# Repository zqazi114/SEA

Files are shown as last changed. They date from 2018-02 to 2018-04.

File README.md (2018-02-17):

# SEA
<h1>
Creative Machines Lab - Smart Electrode Array
</h1>

<h2>OVERVIEW: </h2>
The goal of this project is to design a digitally controlled large array of electrodes. The project will proceed in 3 phases:

<h3>PHASE 1 - </h3>
1. 2-Layer PCB
2. 2" x 2" 
3. No Electronics
4. 4x4 array of comb electrodes

<h3>PHASE 2 - </h3>
1. 4-Layer PCB
2. 6" x 6" 
3. 2 Port Expanders
4. 5V/3.3V on-board power supplies
5. 12VDC Power input
6. USB interface
7. Jumpers for manual connection
8. Debugging
9. 4x4 array of comb electrodes

<h2>BLOCK DIAGRAM:</h2>

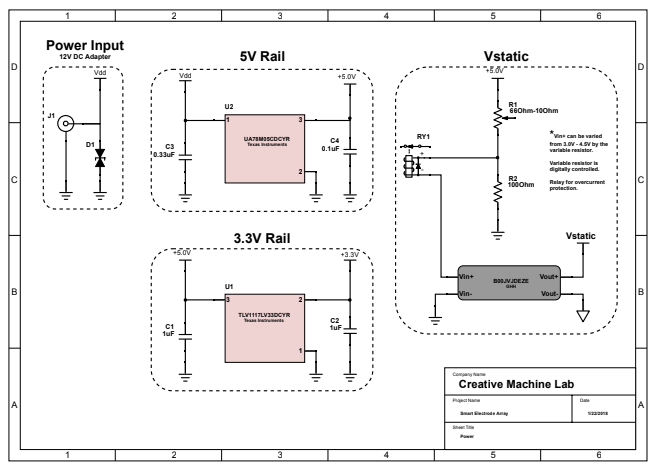
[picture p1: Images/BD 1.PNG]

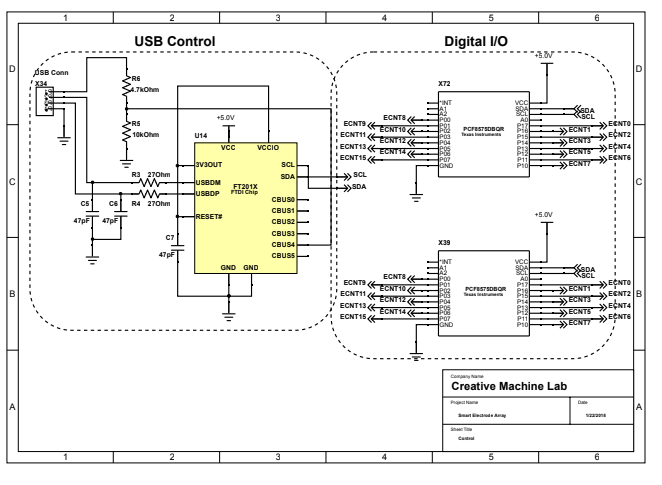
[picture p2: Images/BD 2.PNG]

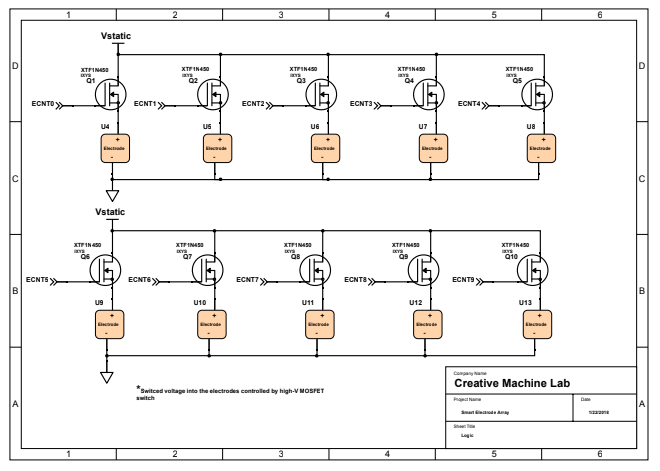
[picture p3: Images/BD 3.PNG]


<h2>FAB A SCHEMATIC:</h2>

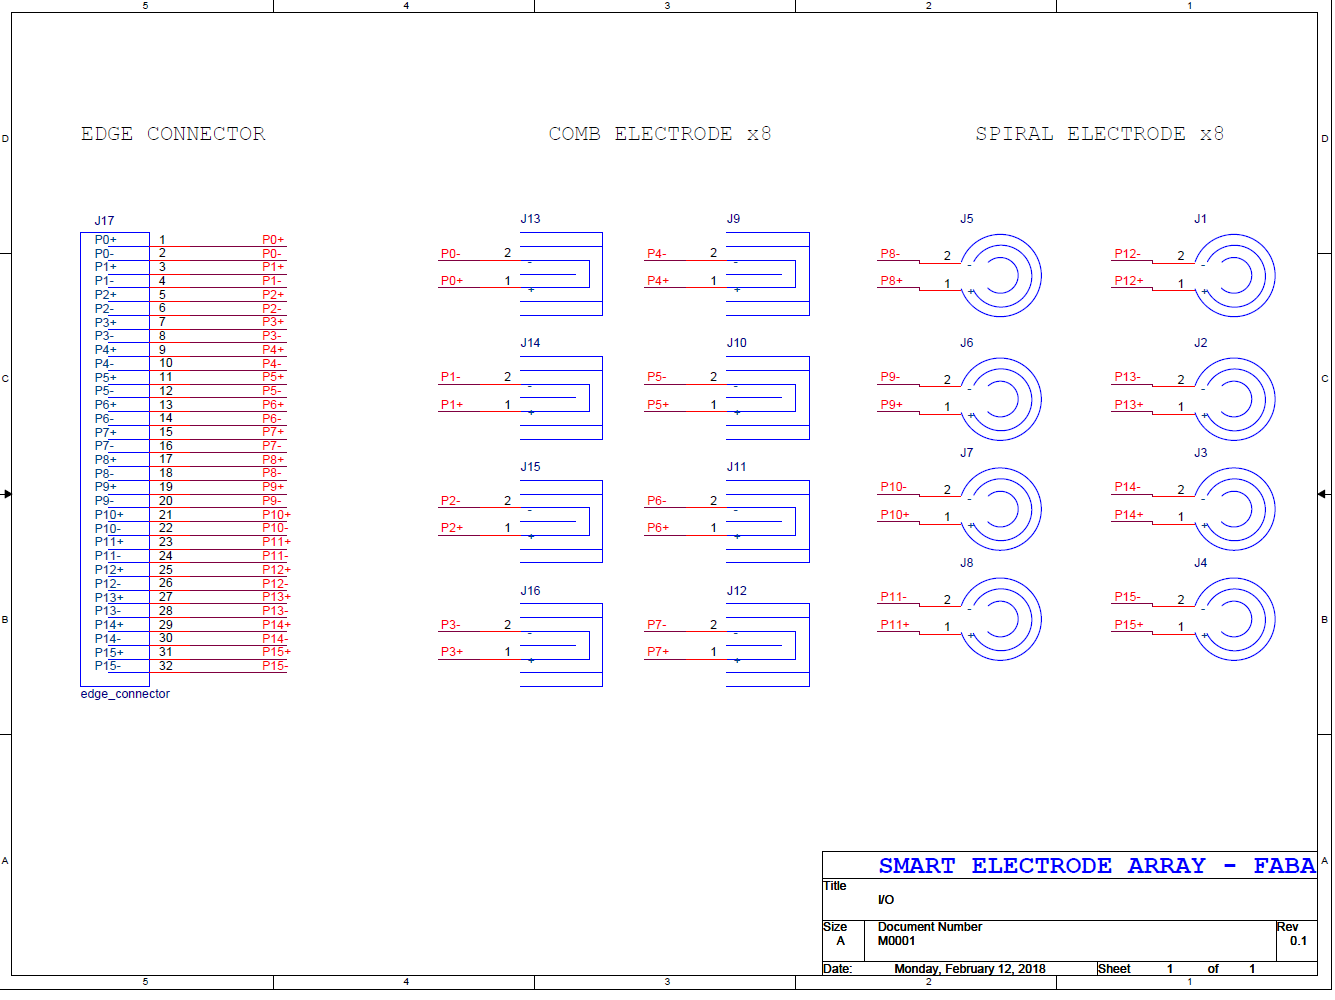
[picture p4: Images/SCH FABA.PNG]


<h2>FAB A LAYOUT:</h2>

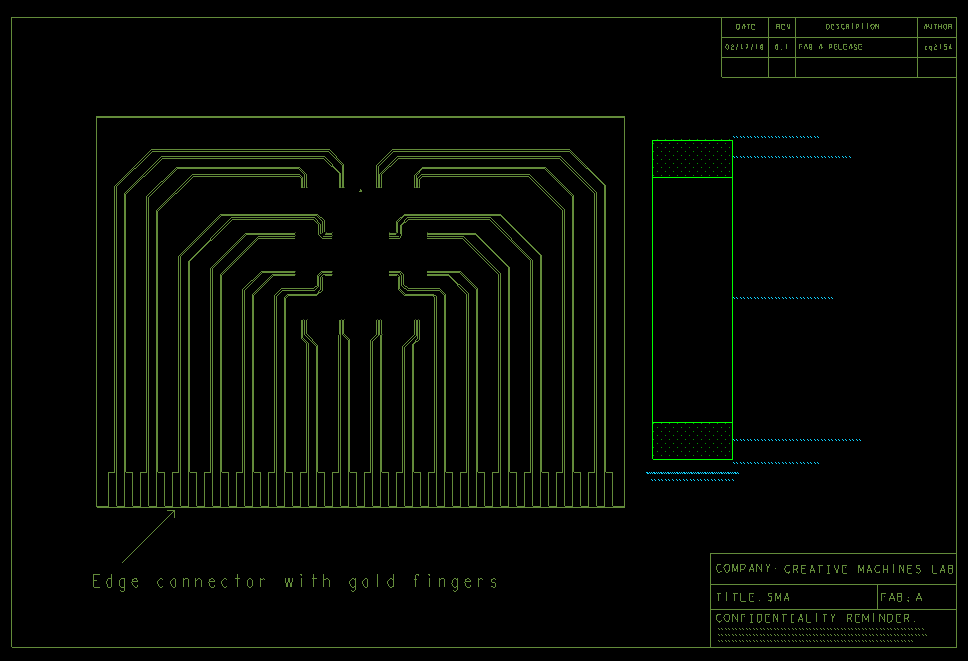
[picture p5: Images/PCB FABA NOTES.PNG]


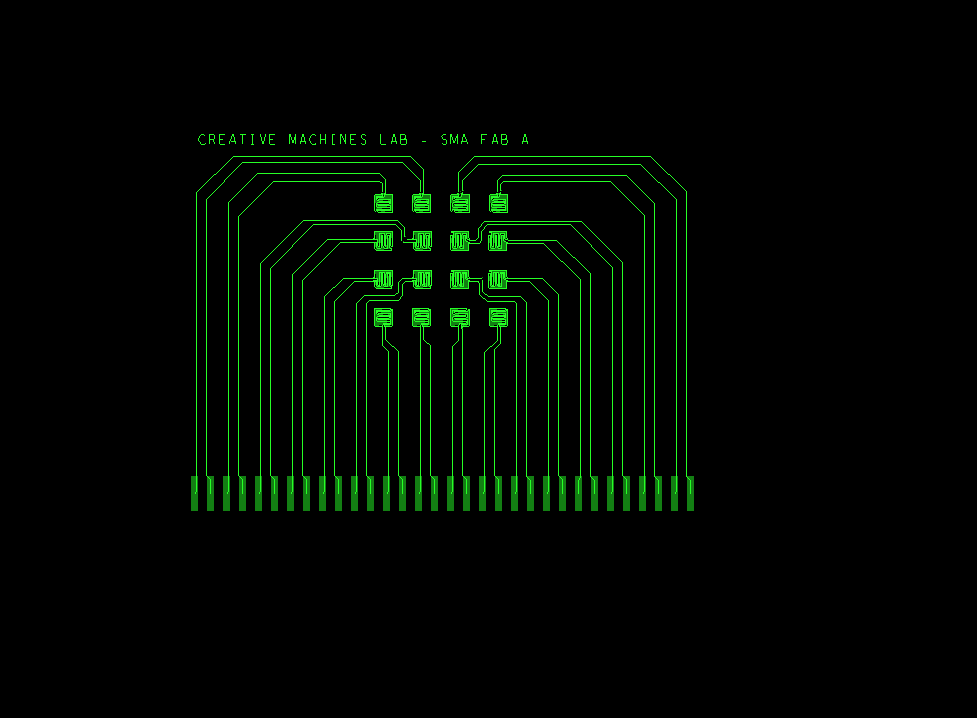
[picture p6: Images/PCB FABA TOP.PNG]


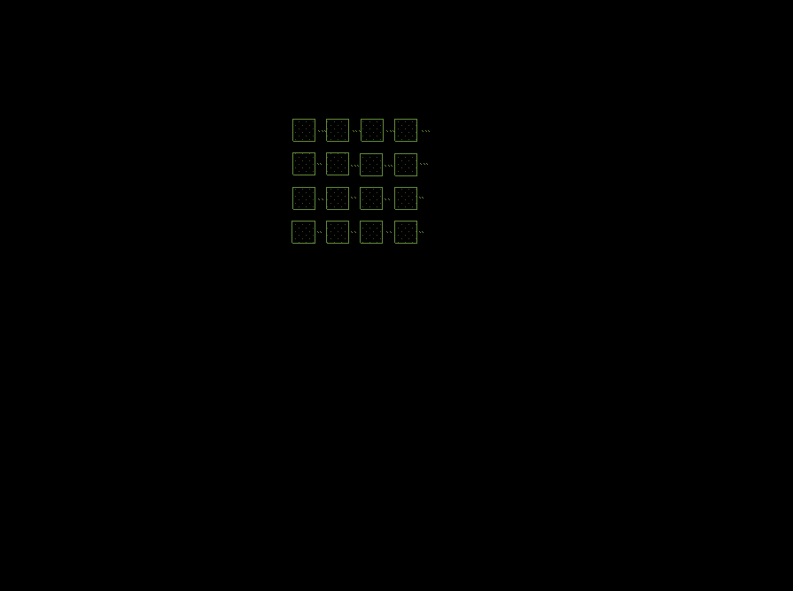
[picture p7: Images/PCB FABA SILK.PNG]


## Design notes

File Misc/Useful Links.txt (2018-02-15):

http://www.flowcad.ch/cms/upload/ApplicationNotes/FlowCAD_AN_PCB_Manufacturing.pdf
https://www.autodesk.com/products/eagle/blog/gerber-nc-drill-pcb-manufacturing-basics-1/
http://www.proto2prod.com/proto2prod/2015/3/18/your-first-prototype-fab-specs-and-gerber-files-13
https://resources.altium.com/pcb-design-blog/how-to-plan-your-pcb-layout-for-a-high-voltage-design
https://resources.altium.com/pcb-design-blog/high-voltage-pcb-design-creepage-and-clearance-distance
http://www.ni.com/tutorial/8584/en/
http://www.4pcb.com/pcb-student-discount.html

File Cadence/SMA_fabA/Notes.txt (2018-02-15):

FAB HOUSE:
http://www.4pcb.com/pcb-prototype-2-4-layer-boards-specials.html
Instructions - 
1. 2 Layer board 60" sq (8" x 8")
2. Minimum of 3
3. FR-4 0.062"
4. 1 oz Cu
5. Green Mask
6. Custom Shape
7. Min 5 mil line/space
8. Min 10 mil hole size
9. No cut-outs
 
1. 4 Layer board 30" sq (6" x 6")
2. Minimum of 4
3. FR-4 0.062"
4. 1 oz Cu
5. Green Mask
6. Custom Shape
7. Min 5 mil line/space
8. Min 10 mil hole size
9. No cut-outs

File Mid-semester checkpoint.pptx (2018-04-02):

## PROTOTYPING

Three Options:
1. PMOS
2. CMOS Inverter
3. Solid State Relay

## OPTION 1 – PMOS

ON STATE :
VIN < VSTAT – VTH ✔
OFF STATE :
VIN > VSTAT – VTH ✖
Unsuccessful.

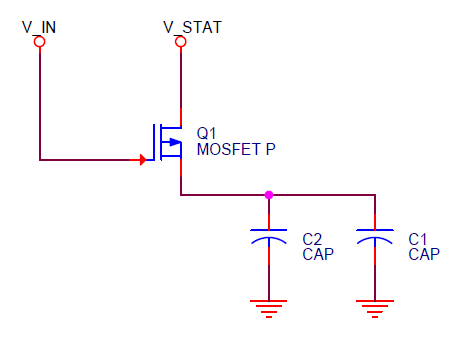
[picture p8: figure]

## OPTION 2 – CMOS

ON STATE :
VIN < VSTAT – VTH ✔
OFF STATE :
VIN > VSTAT – VTH ✖
Unsuccessful.

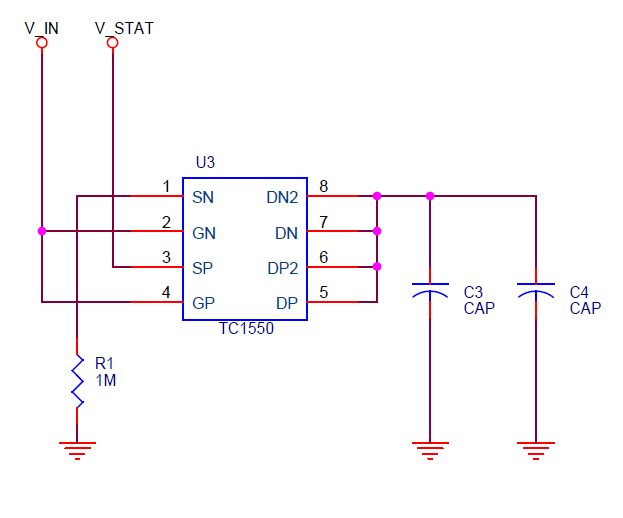
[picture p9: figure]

## OPTION 3 – SSR

ON STATE :
VIN < VSTAT – VTH ✔
OFF STATE :
VIN > VSTAT – VTH ✔
Successful.

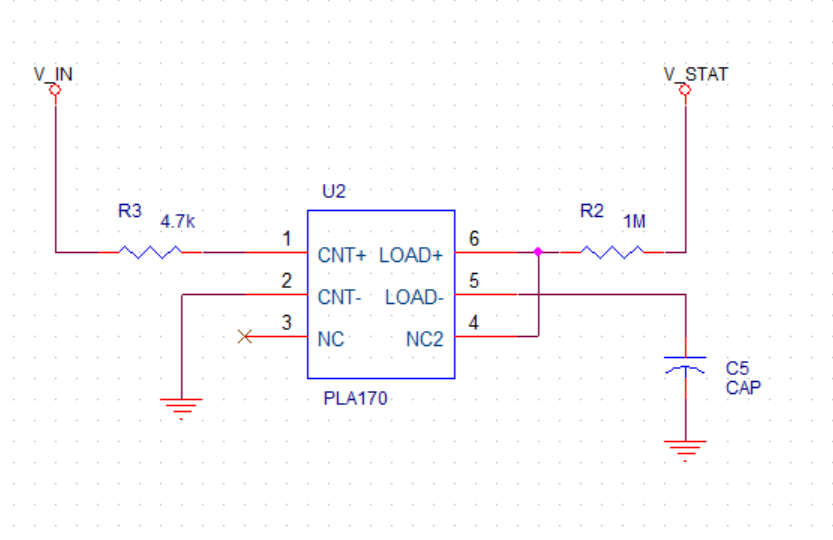
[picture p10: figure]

## PCB DESIGN

We are not expecting static power dissipation
With this scheme, we can experiment with a refresh rate AND measure power dissipation for a parallel On/Off scheme

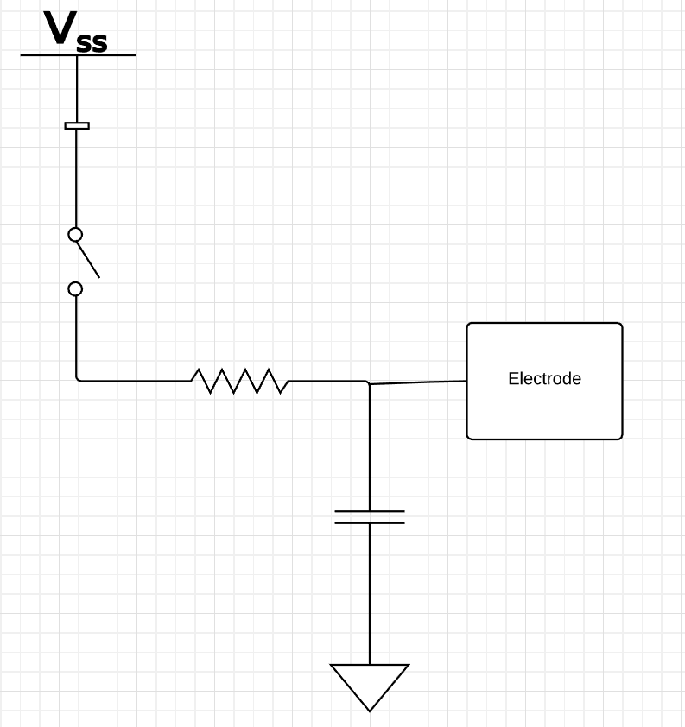
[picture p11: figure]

Off State

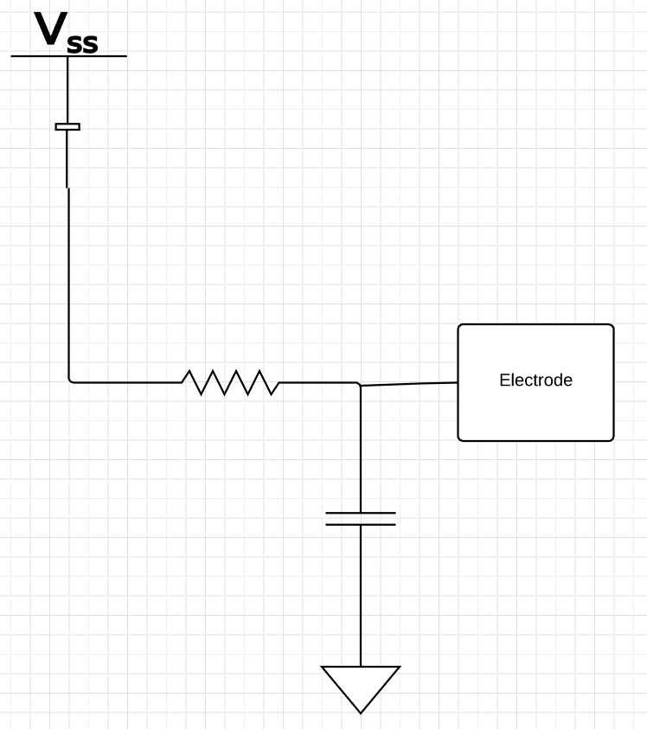
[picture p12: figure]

On State

Circuit

## CHALLENGES

- High inrush current
- Leakage as discharge path

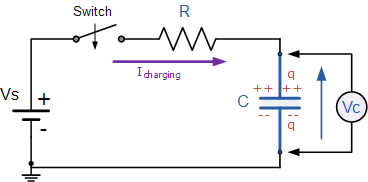
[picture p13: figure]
Image result for rc circuit charging and discharging
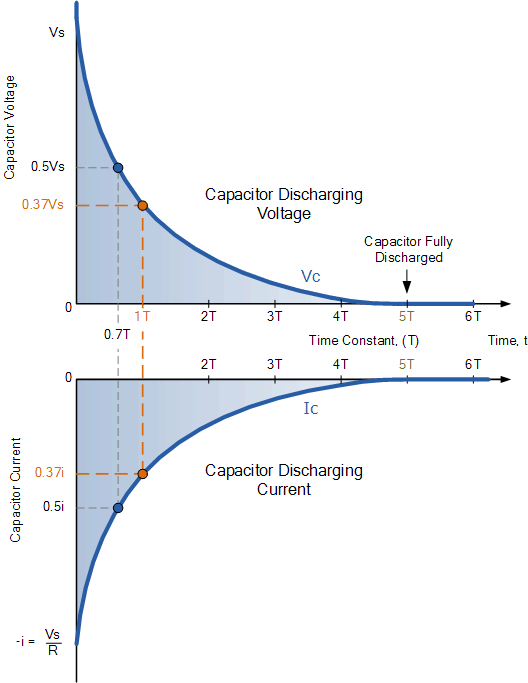
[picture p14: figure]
Image result for rc current plot
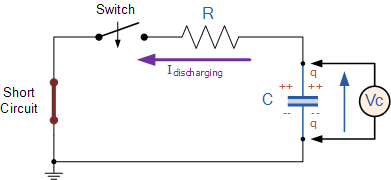
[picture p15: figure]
Related image

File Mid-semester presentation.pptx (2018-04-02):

## Capabilities

Design electronics to digitally control a 4x4 array of electrodes
- 16 independent channels
- Communicate through USB port
- 12VDC power adapter
- Low static power dissipation

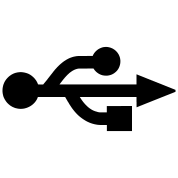
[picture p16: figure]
Image result for usb logo
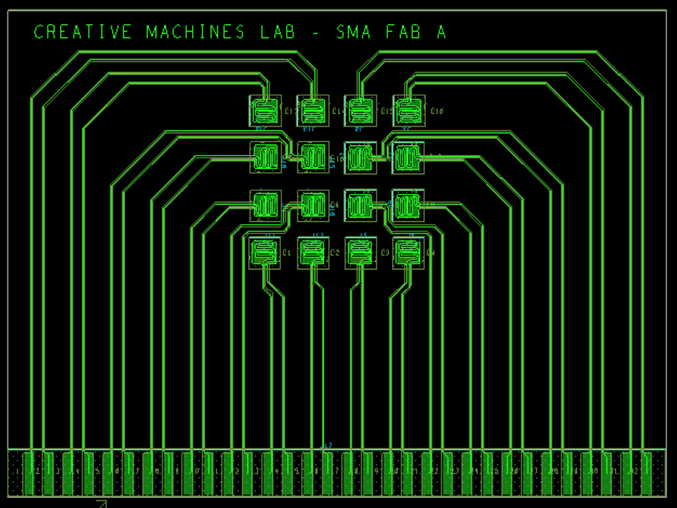
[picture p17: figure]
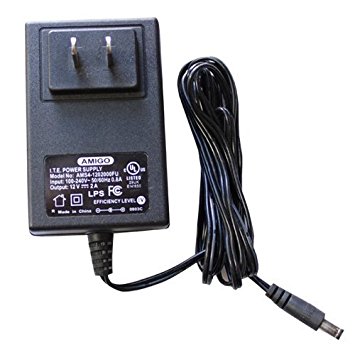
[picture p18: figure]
Image result for 12v dc power adapter

## Block Diagram

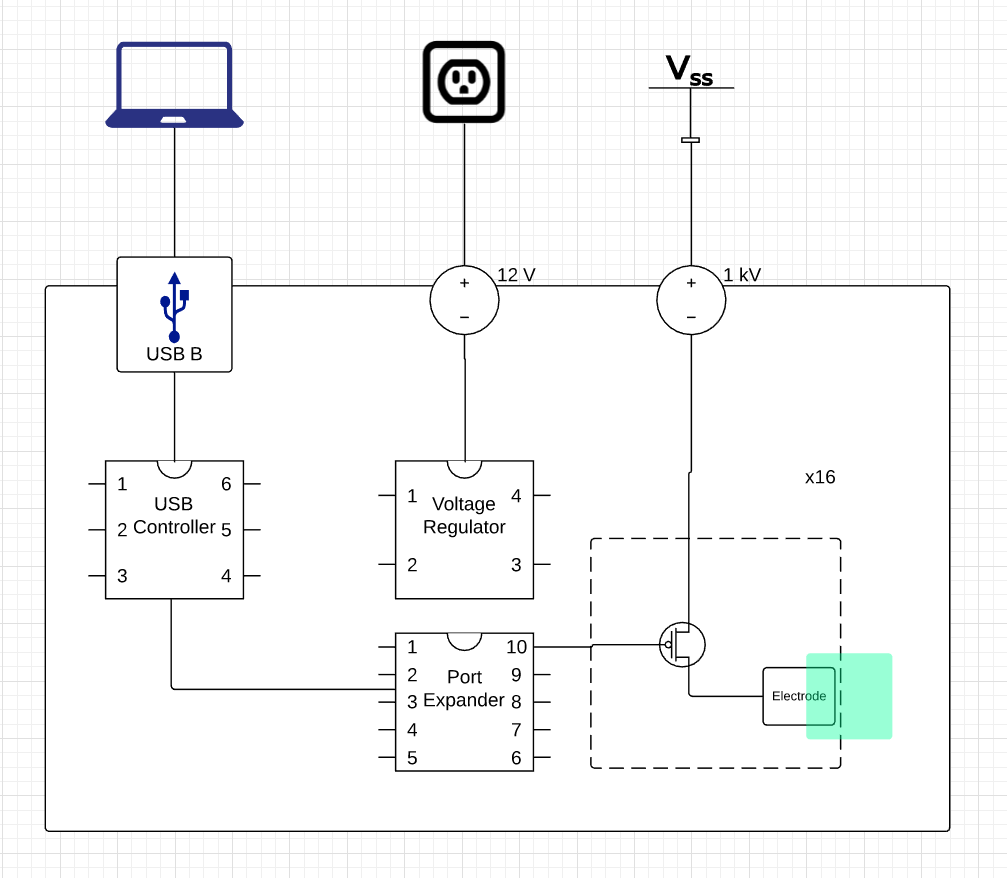
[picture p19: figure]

INPUT
- USB B connector
- 5.5-2.1mm DC jack
IC
- USB Controller
- Port Expander
- VR
- Power Transistors
OUTPUT
- x16 Electrodes

## Prototypes

Test out various dynamic charging schemes
- Single PMOS
- CMOS Inverter
- SSR
{Ongoing}

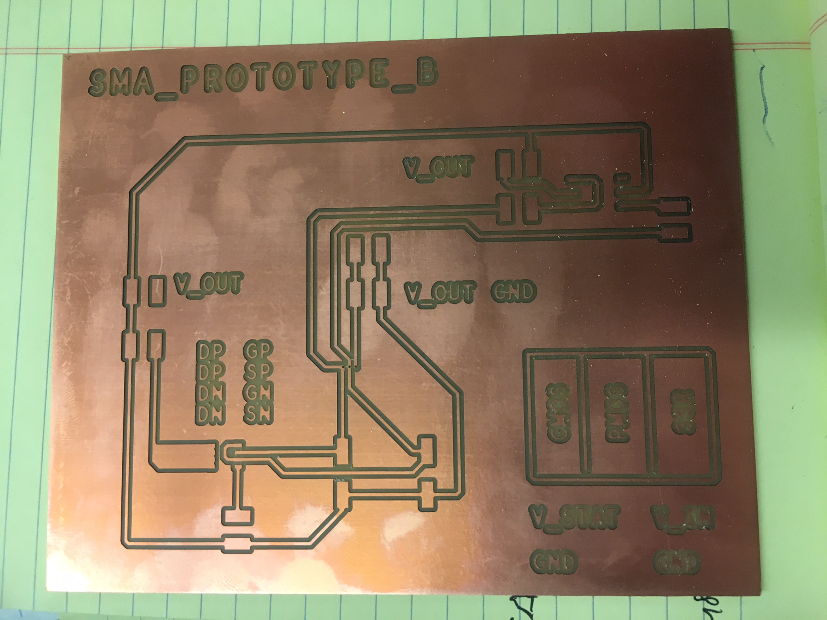
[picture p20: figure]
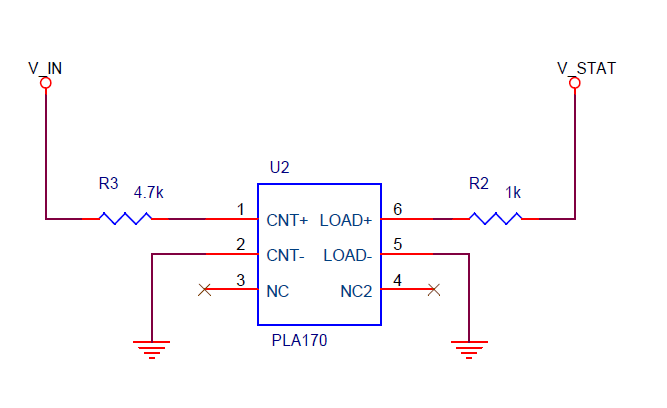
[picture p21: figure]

## Design

Laid out essential components
Completing prototyping activities before
sending out to fab shops

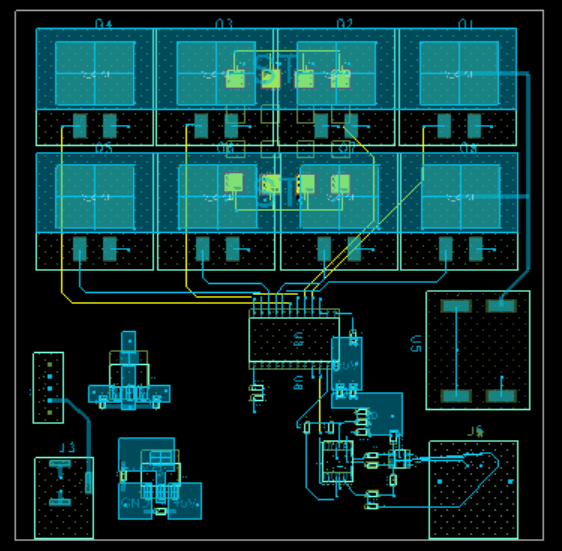
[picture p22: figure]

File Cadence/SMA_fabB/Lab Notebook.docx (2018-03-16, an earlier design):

TOP ISSUES:

# Shared Ground

## Is it alright to connect the high voltage ground to logic ground? Any issues of ground noise coupling?

# Heat loss in MOSFET

## If my MOSFET has an RDS-ON = 25 Ohms, do I risk static power loss during ON/OFF state causing overheating?

## How large should my series resistance be between VSTAT and GND? Do passive components have voltage limits?

## Is there a good design to circumvent static power losses?

# VGS-min required to fully switch MOSFET

## Can the port expander provide sufficient current/voltage to switch the MOSFET?

# Capacitive load of electrode Any risk of back-emf into my MOSFET causing damage?

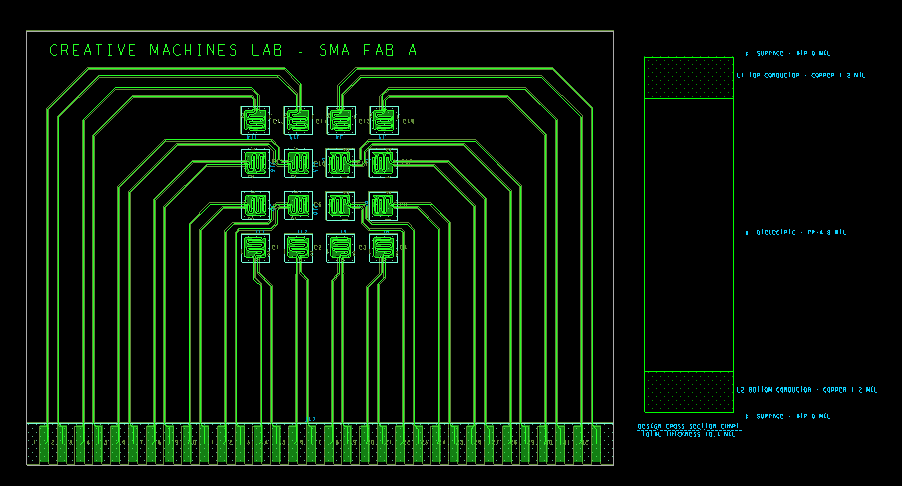
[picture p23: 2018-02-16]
Images/PCB FABA.PNG

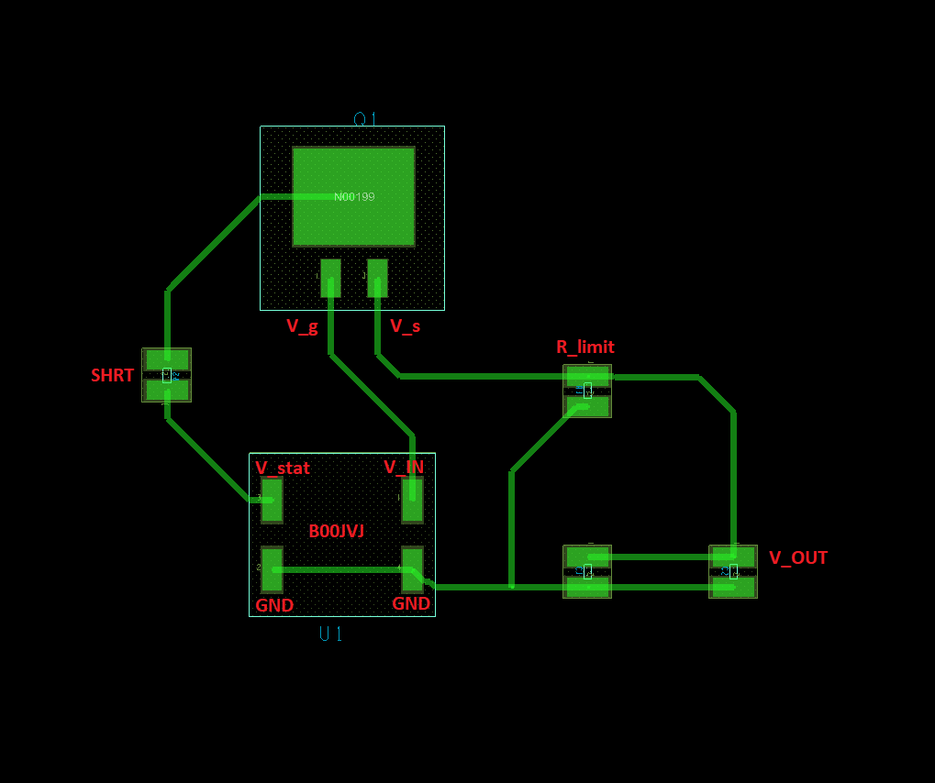
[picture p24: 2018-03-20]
Cadence/SMA_Prototype/Prototype Silkscreen.png

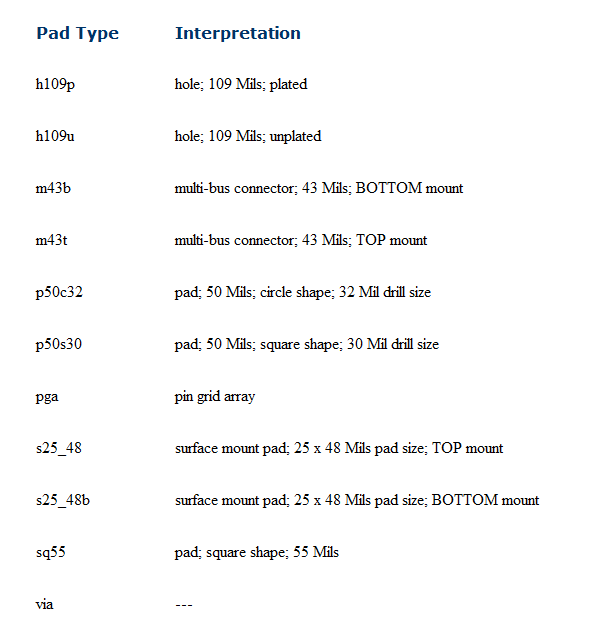
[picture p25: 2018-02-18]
Standards/Pad Naming.PNG

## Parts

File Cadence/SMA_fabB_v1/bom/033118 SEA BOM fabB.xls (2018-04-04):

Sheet: PCBA BOM
Smart Electrode Array BOM (PCBA)
Item # | Ref Des | Qty | Manufacturer | Mfg Part # | Description | Package | Type | Price (USD) | Ext. Price (USD) | Link | Your Instructions
IC
 | U3 | 1 | TI | UA78M05CDCY | IC REG LINEAR 5V 500MA SOT223-4 | SOT-223-4 | SMD | $0.62 | $0.62 | https://www.digikey.com/product-detail/en/texas-instruments/UA78M05CDCY/296-27138-5-ND/1910303 |  | Samples Available
 | U4 | 1 | TI | TLV1117LV33DCYT | IC REG LINEAR 3.3V 1A SOT223-4 | SOT-223-4 | SMD | $0.72 | $0.72 | https://www.digikey.com/product-detail/en/texas-instruments/TLV1117LV33DCYT/296-35976-6-ND/4135114
 | U5 | 1 | YQLTD | B00JVJDEZE | DC Boost Step Up Power Module High Voltage Generator DC 3v-6v To 20kV | Custom | SMD | $8.98 | $8.98 | https://www.amazon.com/Boost-Power-Module-Voltage-Generator/dp/B00JVJDEZE (https://www.digikey.com/product-detail/en/texas-instruments/TLV1117LV33DCYT/296-35976-6-ND/4135114)
 | U8 | 1 | TI | PCF8575DW | IC I/O EXPANDER I2C 16B 24SOIC | SIOC-16 | SMD | $2.86 | $2.86 | https://www.digikey.com/product-detail/en/texas-instruments/PCF8575DW/296-33528-5-ND/1573158
 | U9-U24 | 16 | IXYS | PLA170STR | SSR PCB Mount Single-Pole Relay 800V 100mA | SMD | SMD | $3.39 | $54.24 | https://www.mouser.com/ProductDetail/ixys/pla170str/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
CONNECTOR
 | J3 | 1 | MPD | EJ503A | CONN PWR JACK 2.1X5.5MM SOLDER | Custom | TH | $2.02 | $2.02 | https://www.digikey.com/product-detail/en/mpd-memory-protection-devices/EJ503A/EJ503A-ND/5431753
 | J14 | 1 | C&K | 1103M2S3CQE2 | SWITCH SLIDE SPDT 6A 120V | Custom | TH | $3.64 | $3.64 | https://www.digikey.com/products/en?keywords=1103M2S3CQE2
 | J31 | 1 | Amphenol | 67997-410HLF | CONN HEADER 10POS .100 STR TIN | Custom | TH | $0.27 | $0.27 | https://www.digikey.com/product-detail/en/amphenol-fci/67997-410HLF/609-3243-ND/1878475
 | J32-J34 | 3 | Wurth | 61300311121 | CONN HEADER 3 POS 2.54 | Custom | TH | $0.13 | $0.39 | https://www.digikey.com/product-detail/en/wurth-electronics-inc/61300311121/732-5316-ND/4846825
 | J35 | 1 | Sullins | SBH11-PBPC-D08-ST-BK (https://www.digikey.com/product-detail/en/sullins-connector-solutions/SBH11-PBPC-D08-ST-BK/S9171-ND/1990064) | CONN HEADER 2.54MM 16POS GOLD | Custom | TH | $0.42 | $0.42 | https://www.digikey.com/product-detail/en/sullins-connector-solutions/SBH11-PBPC-D08-ST-BK/S9171-ND/1990064
 | NA | 50 | Sullins | STC02SYAN | CONN JUMPER SHORTING TIN | Custom | TH | $0.10 | $5.00 | https://www.digikey.com/product-detail/en/sullins-connector-solutions/STC02SYAN/S9000-ND/76372
PASSIVE
 | D5 | 1 | Littelfuse Inc. | SA14A | TVS DIODE 14VWM 23.2VC DO204AC | DO-204AC | TH | $0.46 | $0.46 | https://www.digikey.com/product-detail/en/littelfuse-inc/SA14A/SA14ACT-ND/2770381
 | C5 | 1 | TDK | C3216X7R2A334K130AA | 0.33uF Ceramic Cap | 1206 | SMD | $0.57 | $0.57 | https://www.digikey.com/product-detail/en/tdk-corporation/C3216X7R2A334K130AA/445-4464-1-ND/2042260
 | C6,C17 | 2 | Samsung | CL31B104KBCNNNC | 0.1uF Ceramic Cap | 1206 | SMD | $0.10 | $0.20 | https://www.digikey.com/product-detail/en/samsung-electro-mechanics/CL31B104KBCNNNC/1276-1017-1-ND/3889103
 | C7,C8,C16 | 3 | Murata | C1206C105K4RACTU | 1uF Ceramic Cap | 1206 | SMD | $0.23 | $0.69 | https://www.digikey.com/product-detail/en/kemet/C1206C105K4RACTU/399-1254-1-ND/411529
 | C18-C49 | 32 | Kemet | C1206C223KDRACTU | CAP CER 0.022UF 1KV X7R 1206 | 1206 | SMD | $0.38 | $12.16 | https://www.digikey.com/product-detail/en/kemet/C1206C223KDRACTU/399-6746-1-ND/3083920
 | R12,R13,R15 | 3 | Yageo | RC1206JR-074K7L | 4.7kOhm Resistor | 1206 | SMD | $0.10 | $0.30 | https://www.digikey.com/product-detail/en/yageo/RC1206JR-074K7L/311-4.7KERCT-ND/732242
 | R14 | 1 | Yageo | RC1206JR-0710KL | 10kOhm Resistor | 1206 | SMD | $0.10 | $0.10 | https://www.digikey.com/product-detail/en/yageo/RC1206JR-0710KL/311-10KERCT-ND/732156
 | R16-R47 | 32 | Welwyn | HVC1206-10MJT3/ | 10M 1kV | 1206 | SMD | $0.78 | $24.96 | https://www.mouser.com/ProductDetail/Welwyn-Components-TT-Electronics/HVC1206-10MJT3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
 | D7 | 1 | QT | QBLP615-R | Red LED | 1206 | SMD | $0.10 | $0.10 | https://www.digikey.com/product-detail/en/qt-brightek-qtb/QBLP615-R/1516-1076-2-ND/4814674
 | D6 | 1 | QT | QBLP615-IB | Blue LED | 1206 | SMD | $0.50 | $0.50 | https://www.digikey.com/product-detail/en/qt-brightek-qtb/QBLP615-IB/1516-1072-1-ND/4814799
 | D4 | 1 | QT | QBLP615-Y | Yellow LED | 1206 | SMD | $0.41 | $0.41 | https://www.digikey.com/product-detail/en/qt-brightek-qtb/QBLP615-Y/1516-1077-1-ND/4814804
 | J15-J30 | 16 | NA | NA | Comb Electrode | NA | SMD | $0.00 | $0.00
 |  |  |  |  |  |  |  | TOTAL | $119.61
 |  |  |  |  |  |  |  | w/o MOS | $65.37

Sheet: Other BOM
Smart Electrode Array BOM (OTHER)
Item # | Qty | Manufacturer | Mfg Part # | Description | Price (USD) | Link | Your Instructions
1 | 1 | XP-Power | VEL05US120-US-JA | AC/DC WALL MOUNT ADAPTER 12V 5W | $6.50 | https://www.digikey.com/product-detail/en/xp-power/VEL05US120-US-JA/1470-2774-ND/5023716
2 | 1 | Aardvark | TP240141 | Aardvark I2C/SPI Host Adapter | $285.00 | https://www.totalphase.com/catalog/product/view/id/2/s/aardvark-i2cspi/
3
4
5
 |  |  |  | TOTAL | $291.50

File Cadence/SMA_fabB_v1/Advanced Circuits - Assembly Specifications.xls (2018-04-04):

 | ~ PCB Fabrication & Assembly All Under One Roof ~
Assembly Order Type
X | Full Turn-Key | Select - if you want Advanced Circuits / One Stop Assembly to purchase ALL components.
(Minimum quantity is 5) |  | Please request budgetary quotes and quotes from preliminary BOMS as labor only.
 |  | We will be pleased to quote material pricing once your BOM has been finalized.
 | Labor Only | Select - if you would like a LABOR ONLY QUOTE and you will be supplying / sending
(No Minimum Qty) |  | ALL components.
 | Partial Turn-Key | Select - if you will be sending some components. ***
*** - Identify the components you will be supplying on your BOM as “Customer Supplied”. If you have components you do not
want installed, identify them as DNI or DNP (Do Not Install / Populate).
Assembly Type |  | X | New Assembly |  |  |  | Previous Work Order / PO #
Re-orders without change (RONC) - Labor Discounts may apply
Assemblies will be manufactured in accordance with IPC 610 Class II Workmanship Standards
 |  | Build Qty | 1 |  | Build Qty | 5 |  | Build Qty | 10
These quantities will be shipped as a single lot / weekly / monthly / quarterly / annually
Assembly Part Number
Revision
PCB Dimension **(inches) |  | 4.19 |  |  | X | 3.57
** - If your PCB has a dimension less than < 2” it must be panelized in an array for assembly or it may increase your labor
cost, contact your Assembly Sales Manager or Associate for array details.
Depanel |  |  | Yes | X | No |  | N/A
(PCBAs being assembled in an array can be shipped individually or in the complete array)
SMT Components on both sides |  |  | Yes | X | No
Lead Free Processing (RoHS) ** |  |  | Yes |  | No | X
** - Lead-free BGAs will require (RoHS) lead-free processing
ITAR Compliance – Code M |  |  | Yes |  | No | X
Click Here - For more information whether or not your assembly data is ITAR-controlled go to http://en.wikipedia.org/wiki/ITAR.
Forward a copy of the completed assembly specifications, an electronic (EXCEL) copy of your Bill of Materials
and gerber files to your Advanced Circuits Assembly Sales Manager or Associate. Online labor quotes are also
available @ www.onestopassembly.com, use your same login and password from your www.4pcb.com account.
Company / Customer Information
Company Name |  | Columbia University - Creative Machines Lab
Technical / Contact Name |  | Zain Qazi
Phone Number / Email |  | 2172553382 / zq2154@columbia.edu
Additional Notes:
P:\ASSEMBLY QUOTES\Assembly Specification .xls |  |  |  |  |  |  |  | Revised 4/4/2013

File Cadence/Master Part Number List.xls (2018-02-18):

Smart Electrode Array BOM (PCBA)
PART NUMBER | Manufacturer | Mfg Part # | Description | Package | Type | Price (USD) | Link | Your Instructions
IC
N0001 | TI | UA78M05CDCY | IC REG LINEAR 5V 500MA SOT223-4 | SOT-223-4 | SMD | $0.62 | https://www.digikey.com/product-detail/en/texas-instruments/UA78M05CDCY/296-27138-5-ND/1910303 |  | Samples Available
N0002 | TI | TLV1117LV33DCYT | IC REG LINEAR 3.3V 1A SOT223-4 | SOT-223-4 | SMD | $0.72 | https://www.digikey.com/product-detail/en/texas-instruments/TLV1117LV33DCYT/296-35976-6-ND/4135114
N0003 | YQLTD | B00JVJDEZE | DC Boost Step Up Power Module High Voltage Generator DC 3v-6v To 20kV | Custom | SMD | $8.98 | https://www.amazon.com/Boost-Power-Module-Voltage-Generator/dp/B00JVJDEZE (https://www.digikey.com/product-detail/en/texas-instruments/TLV1117LV33DCYT/296-35976-6-ND/4135114)
N0004 | Microchip | MCP4017 | Digital Potentiometer - 10k | SO-70 | SMD | $1.50 | https://www.sparkfun.com/products/10613 | Find larger package
N0005 | FTDI | FT201X | Full Speed USB to I2C Bridge | SSOP-16 | SMD | $2.15 | http://www.ftdichip.com/Products/ICs/FT201X.html
N0006 | TI | PCF8575DW | IC I/O EXPANDER I2C 16B 24SOIC | SIOC-16 | SMD | $2.86 | https://www.digikey.com/product-detail/en/texas-instruments/PCF8575DW/296-33528-5-ND/1573158
N0007 | STMicroelectronics | STFW3N150 | MOSFET N-channel 1500 V 2.5 A PowerMESH | Custom | TH | $3.84 | https://www.mouser.com/ProductDetail/STMicroelectronics/STFW3N150 | Need to find cheaper alternative
N0008
N0009
N0010
N0011
N0012
N0013
CONNECTOR
N4001 | MPD | EJ503A | CONN PWR JACK 2.1X5.5MM SOLDER | Custom | TH | $2.02 | https://www.digikey.com/product-detail/en/mpd-memory-protection-devices/EJ503A/EJ503A-ND/5431753
N4002 | Assmann | AU-Y1007 | CONN USB RTANG FEMALE TYPE B PCB | Custom | TH | $0.74 | https://www.digikey.com/product-detail/en/assmann-wsw-components/AU-Y1007/AE11183-ND/278928
N4003
N4004
N4005
N4006
N4007
PASSIVE
N5001 | Murata | PRG18BB471MB1RB | PTC RESET FUSE 24V 10MA 0603 | 0603 | SMD | $0.54 | https://www.digikey.com/product-detail/en/murata-electronics-north-america/PRG18BB471MB1RB/490-2473-6-ND/1825663
N5002 | Littelfuse Inc. | SA14A | TVS DIODE 14VWM 23.2VC DO204AC | DO-204AC | TH | $0.46 | https://www.digikey.com/product-detail/en/littelfuse-inc/SA14A/SA14ACT-ND/2770381
N5003 | STMicroelectronics | USBLC6-2SC6 | TVS DIODE 5.25VWM 17VC SOT23-6 | SOT-23-6 | SMD | $0.42 | https://www.digikey.com/product-detail/en/stmicroelectronics/USBLC6-2SC6/497-5235-6-ND/1121704
N5004 |  |  | 0.33uF Ceramic Cap | 0603 | SMD
N5005 |  |  | 0.1uF Ceramic Cap | 0603 | SMD
N5006 |  |  | 1uF Ceramic Cap | 0603 | SMD
N5007 |  |  | 47uF Ceramic Cap | 0603 | SMD
N5008
N5009
N5010 |  |  | 50kOhm Resistor | 0603 | SMD
N5011 |  |  | 4.7kOhm Resistor | 0603 | SMD
N5012 |  |  | 10kOhm Resistor | 0603 | SMD
N5013 |  |  | 27Ohm Resistor | 0603 | SMD
N5014
N5015
N5016

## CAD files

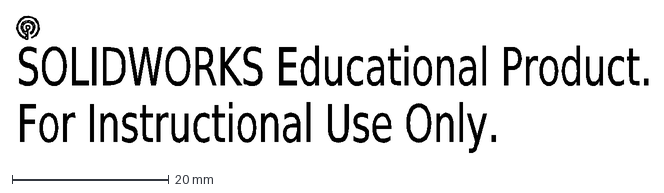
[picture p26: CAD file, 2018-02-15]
Cadence/SMA_fabA/layout/dxf/spiral_5_mil_a.DXF
SOLIDWORKS Educational Product.
For Instructional Use Only.

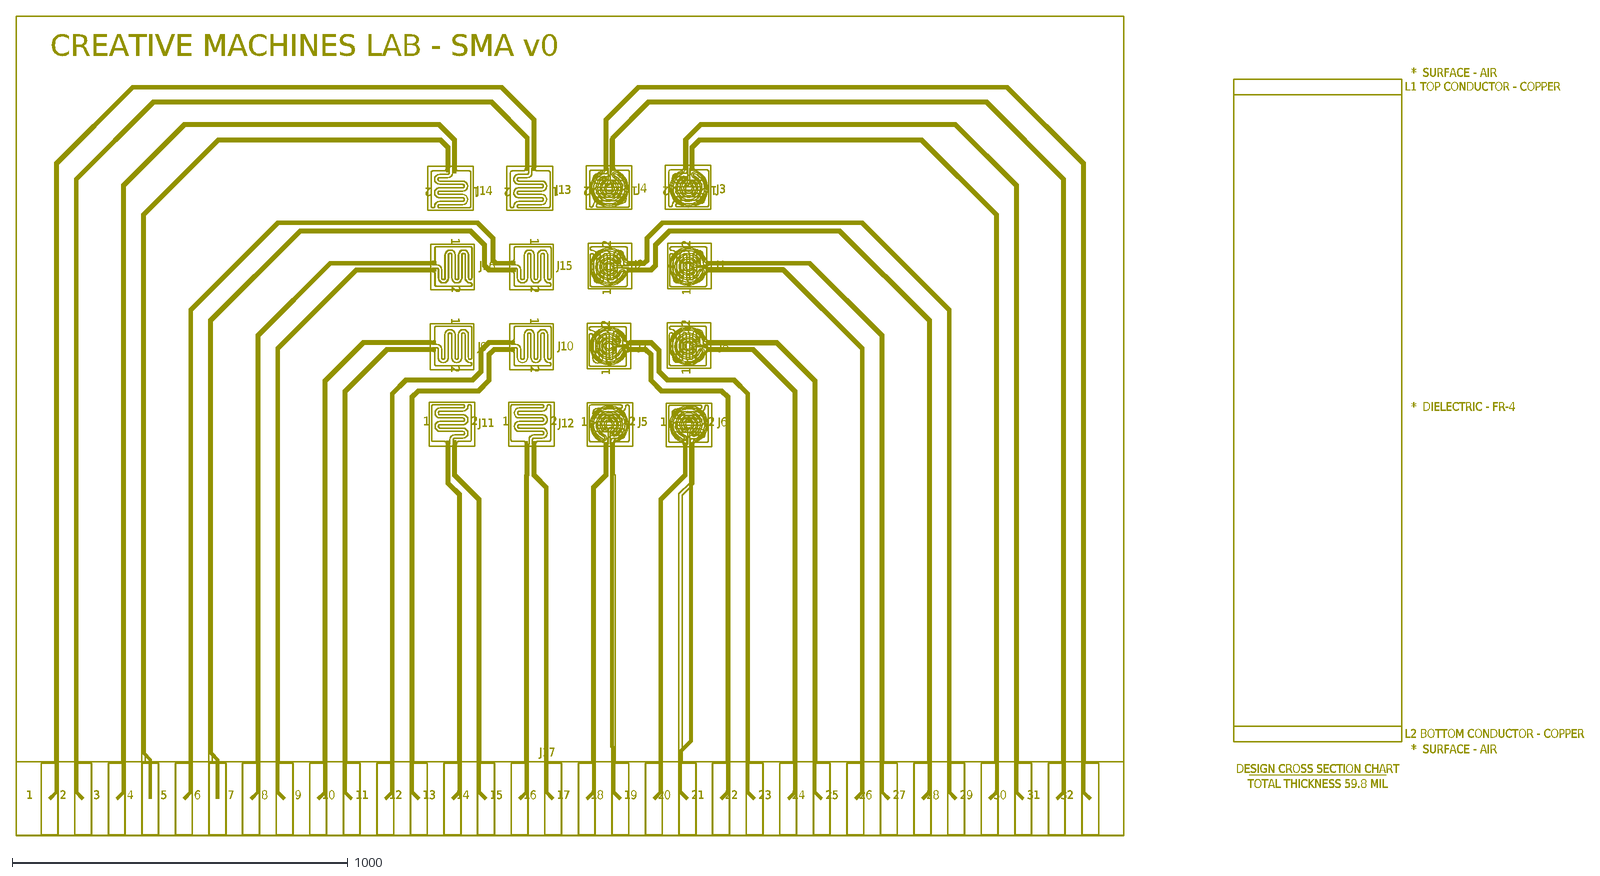
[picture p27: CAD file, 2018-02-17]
Cadence/SMA_fabA/layout/SMA_fabA.dxf
1
2
J16
J15
J14
J13
J12
J11
J10
J9
J8
J7
J6
J5
J4
J3
J2
J1
3
4
5
6
7
8
9
10
11
12
13
14
15
16
17
18
19
20
21
22
23
24
25
26
27
28
29
30
31
32
J17
CREATIVE MACHINES LAB - SMA v0
TOTAL THICKNESS 59.8 MIL
___________________________
DESIGN CROSS SECTION CHART
* SURFACE - AIR
L2 BOTTOM CONDUCTOR - COPPER
* DIELECTRIC - FR-4
L1 TOP CONDUCTOR - COPPER

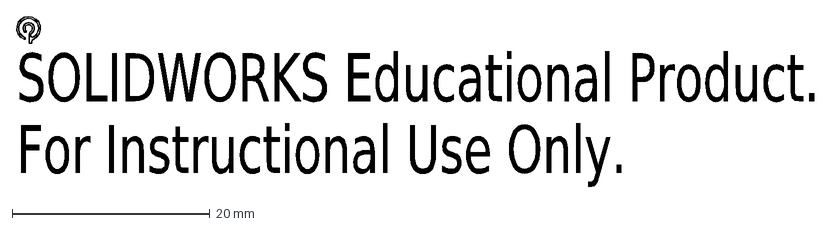
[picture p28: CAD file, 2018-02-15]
Cadence/SMA_fabA/layout/dxf/spiral_5_mil_b.DXF
SOLIDWORKS Educational Product.
For Instructional Use Only.

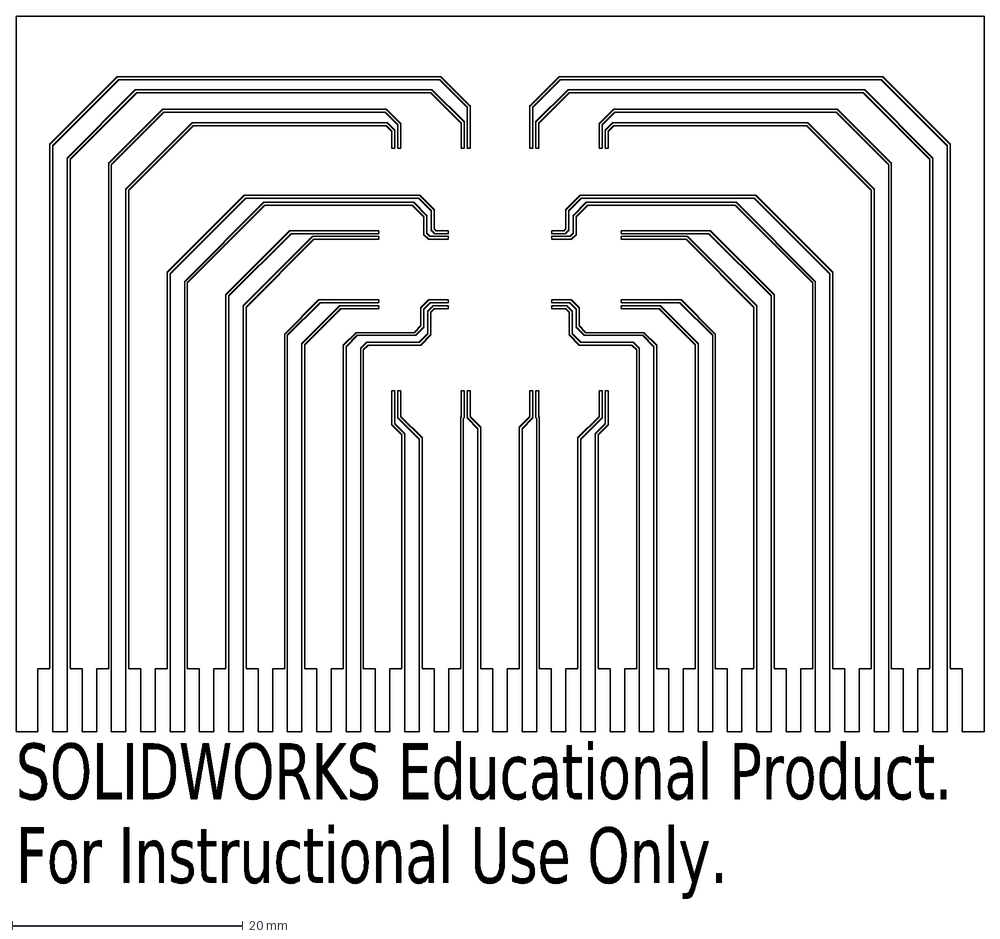
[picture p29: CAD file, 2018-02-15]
Cadence/SMA_fabA/layout/dxf/board_electrode_skeleton_4x4.DXF
SOLIDWORKS Educational Product.
For Instructional Use Only.

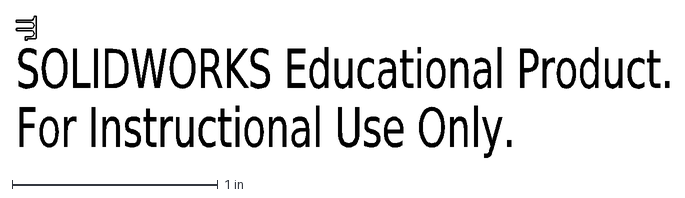
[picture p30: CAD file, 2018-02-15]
Cadence/SMA_fabA/layout/dxf/comb_10_mil_b.DXF
SOLIDWORKS Educational Product.
For Instructional Use Only.

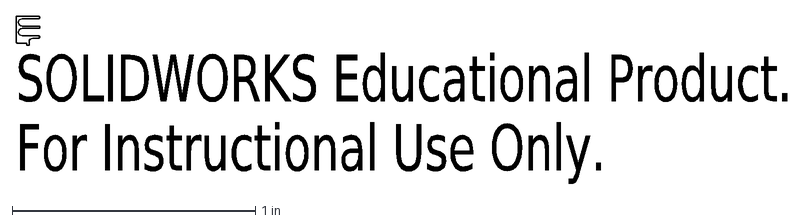
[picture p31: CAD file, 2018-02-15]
Cadence/SMA_fabA/layout/dxf/comb_10_mil_a.DXF
SOLIDWORKS Educational Product.
For Instructional Use Only.

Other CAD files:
Cadence/SMA_Prototype/layout/SMA_Prototype.dxf
Cadence/SMA_fabA/layout/au-y1007.psm
Cadence/SMA_fabA/layout/comb_electrode.psm
Cadence/SMA_fabA/layout/edge_connector.psm
Cadence/pcb_lib/old/0603_r.psm
Cadence/pcb_lib/old/au-y1007.psm
Cadence/pcb_lib/old/b00jvjdeze.psm
Cadence/pcb_lib/old/comb_electrode_full.psm
Cadence/pcb_lib/old/ej503a.psm
Cadence/pcb_lib/old/ft201x.psm
Cadence/pcb_lib/old/large_r_c.psm
Cadence/pcb_lib/old/os102011ms2qn1.psm
Cadence/pcb_lib/old/pcf8575dw.psm
Cadence/pcb_lib/old/pla170.psm
Cadence/pcb_lib/old/sa14a.psm
Cadence/pcb_lib/old/stfw3n150.psm
Cadence/pcb_lib/old/tc1550.psm
Cadence/pcb_lib/old/tlv1117lv33dcyt.psm
Cadence/pcb_lib/old/ua78m05cdcy.psm
Cadence/pcb_lib/old/usblc6-2sc6.psm
Cadence/pcb_lib/old/vp0550-1.psm
Cadence/pcb_lib/old/vp0550.psm
Cadence/pcb_lib/symbols/0603_r.psm
Cadence/pcb_lib/symbols/1103m2s3cqe2.psm
Cadence/pcb_lib/symbols/1206_c.psm
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

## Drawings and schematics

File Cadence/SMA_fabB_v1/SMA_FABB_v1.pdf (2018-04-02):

12V IN DC JACK | 12V TO 5V VR

# 5V TO V_STAT

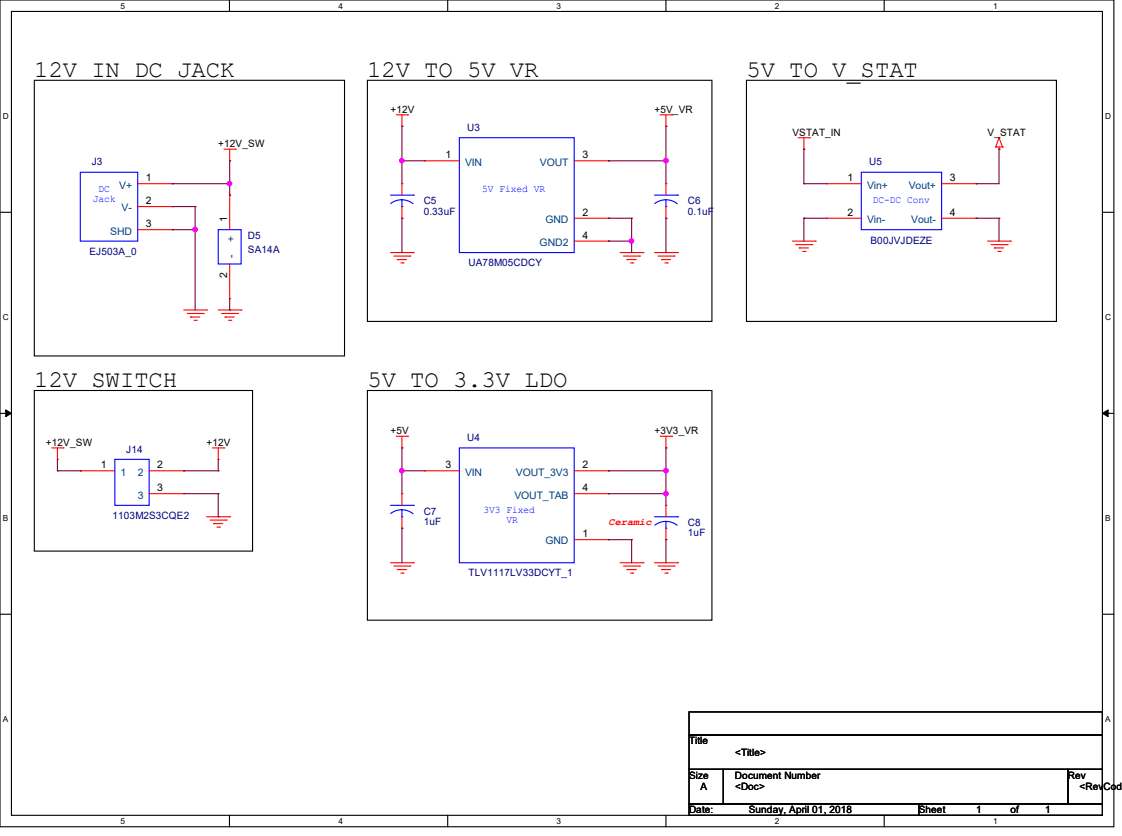
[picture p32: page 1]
12V SWITCH; 5V TO 3.3V LDO; Ceramic; VSTAT_IN; V_STAT; Title Size; Document Number; Rev Date:; Sheet; of <Doc>; <RevCode>; <Title> A; Sunday, April 01, 2018; 1 Title Size; 1103M2S3CQE2; 3 3V3 Fixed; VR U4TLV1117LV33DCYT_1 VIN 3; VOUT_3V3 2 GND 1 VOUT_TAB 4; DC Jack; 2 SHD 3; Vin+ 1 Vin- 2; Vout+ 3 Vout-; 4 5V Fixed VR U3UA78M05CDCY; VIN 1; VOUT 3 GND 2 GND2 D5

DC-DC Conv U5B00JVJDEZE

# USB Type B Conn

# USB TO I2C BRIDGE

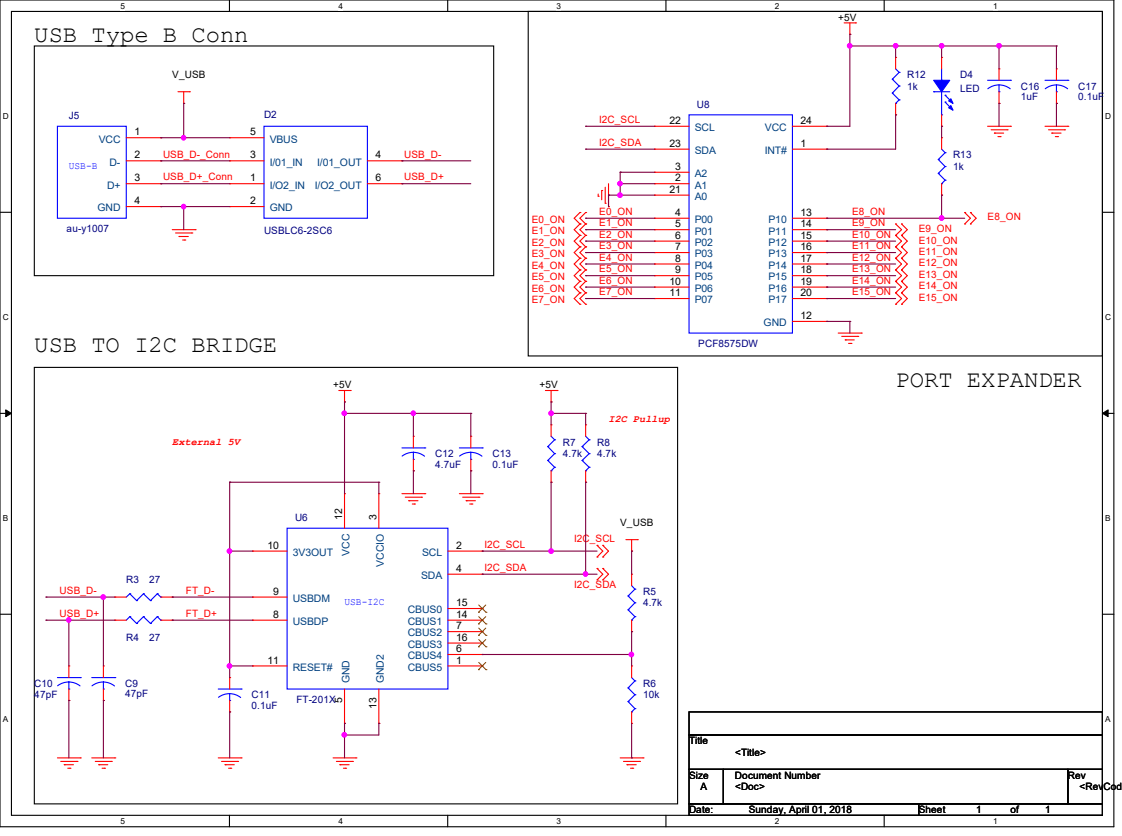
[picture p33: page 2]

# GPIO 0-7

# 2 C33

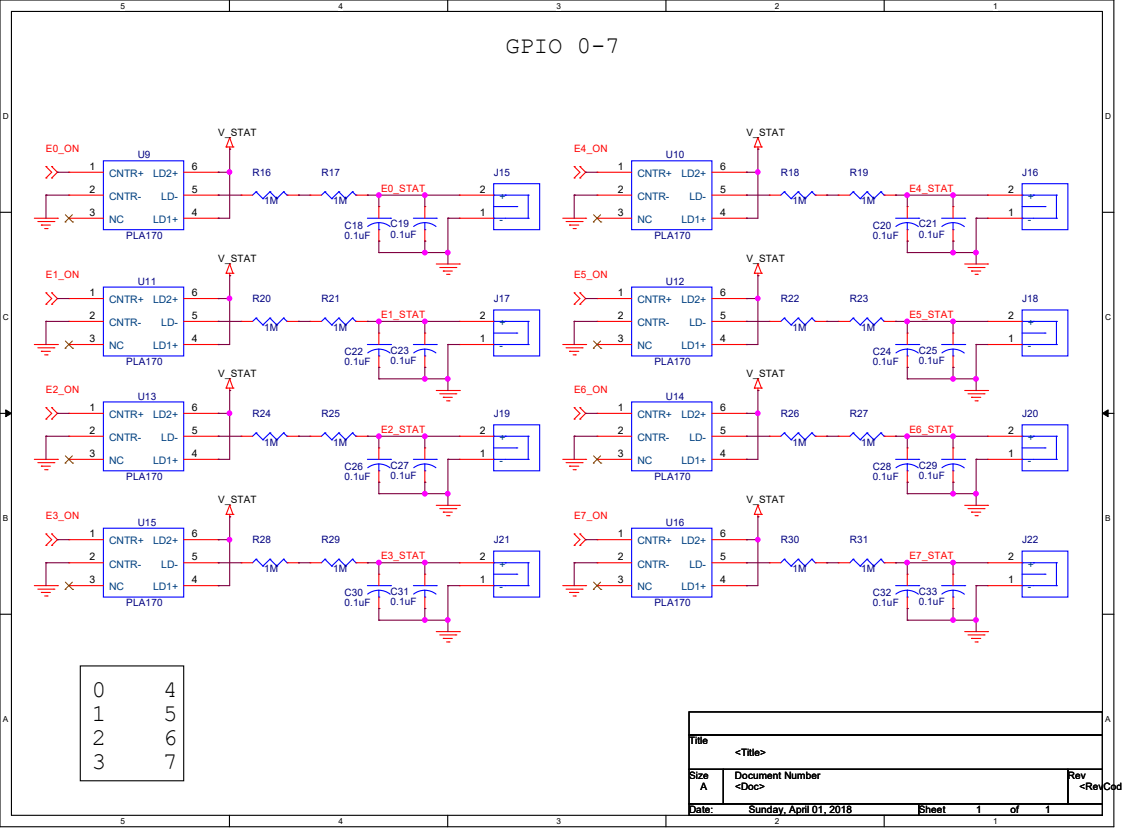
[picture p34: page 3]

# GPIO 8-15

# 0.1uF R43

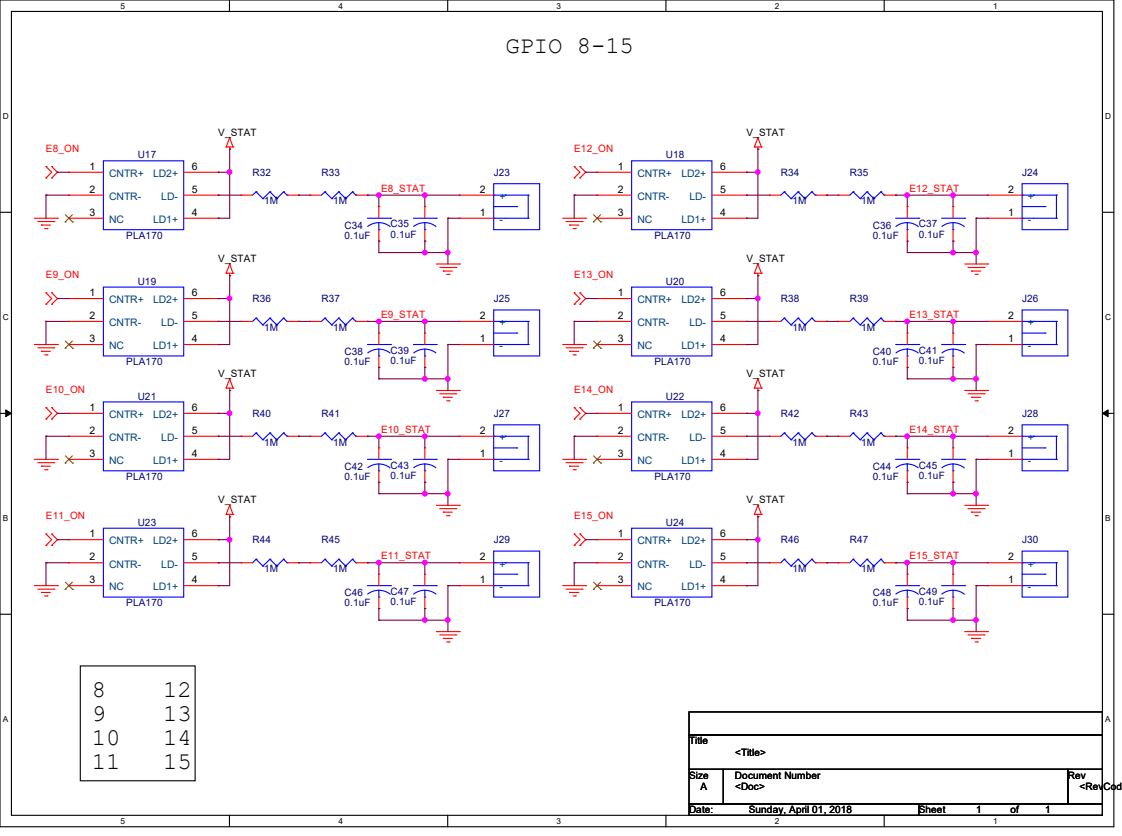
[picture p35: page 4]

# DEBUG

UART | LEDS | VSTAT_IN SELECT

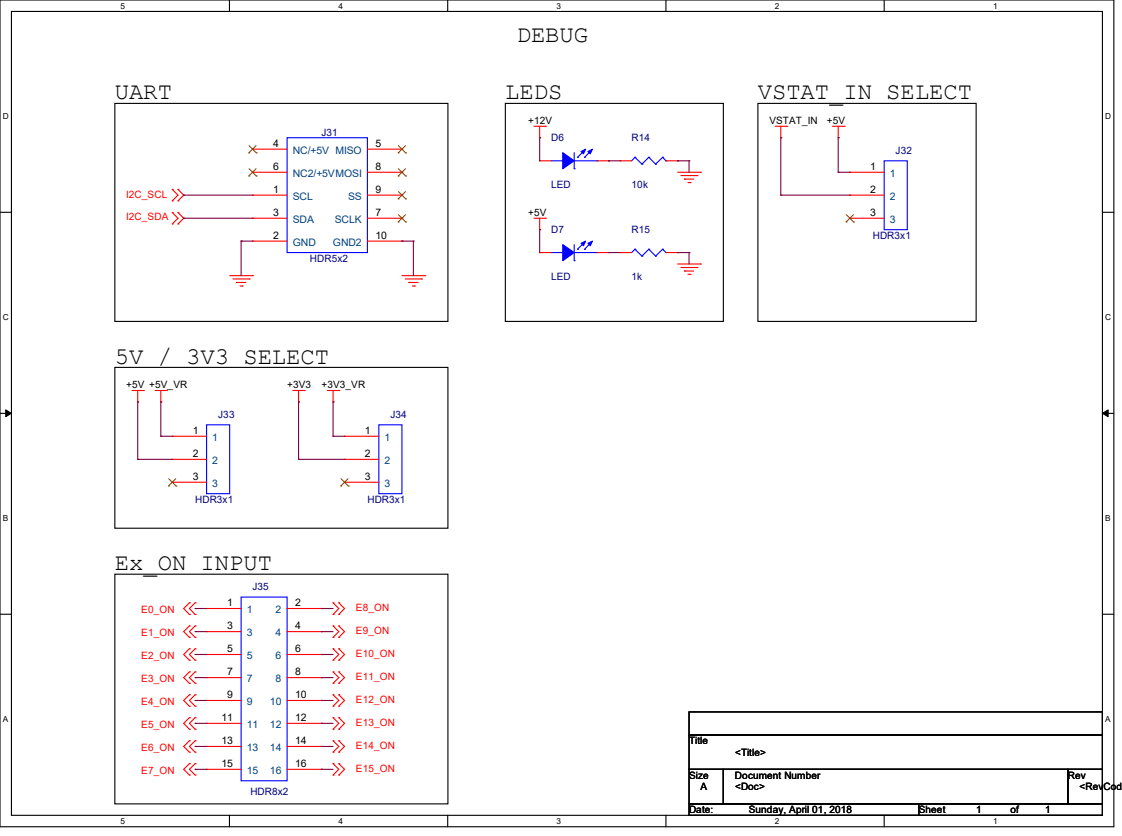
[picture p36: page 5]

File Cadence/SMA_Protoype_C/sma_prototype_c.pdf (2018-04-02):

# POWER

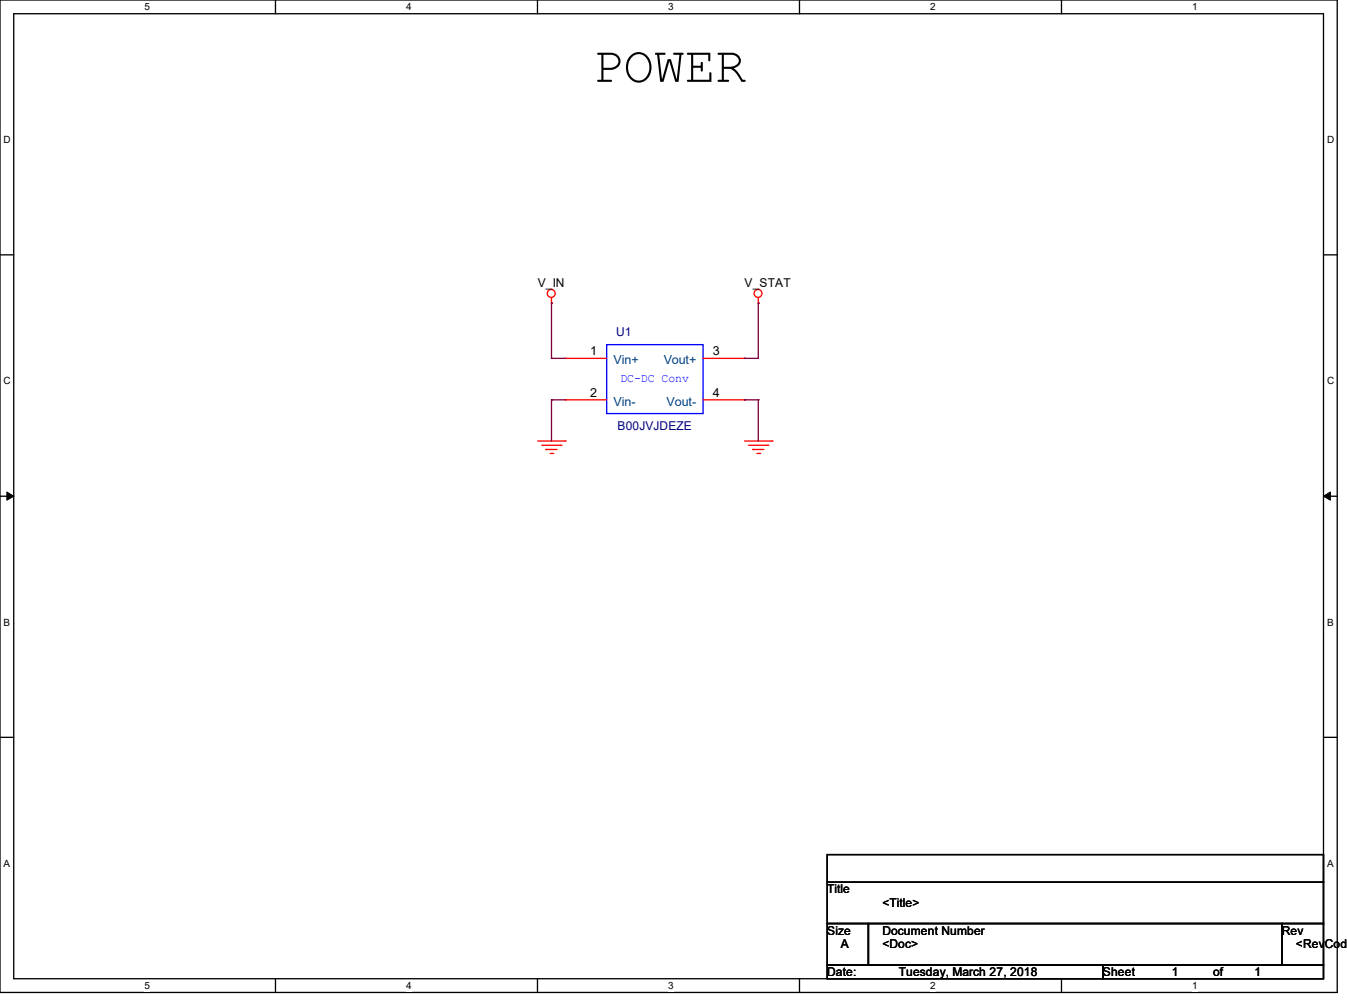
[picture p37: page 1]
V_STAT; Title; Size; Document Number; Rev; Date:; Sheet; <Doc>; <RevCode>; <Title>; Tuesday, March 27, 2018; B00JVJDEZE; Vin+ 1; Vout+; Vout-

DC-DC Conv
Vin- 2

| V_STAT | OPTO-SSR

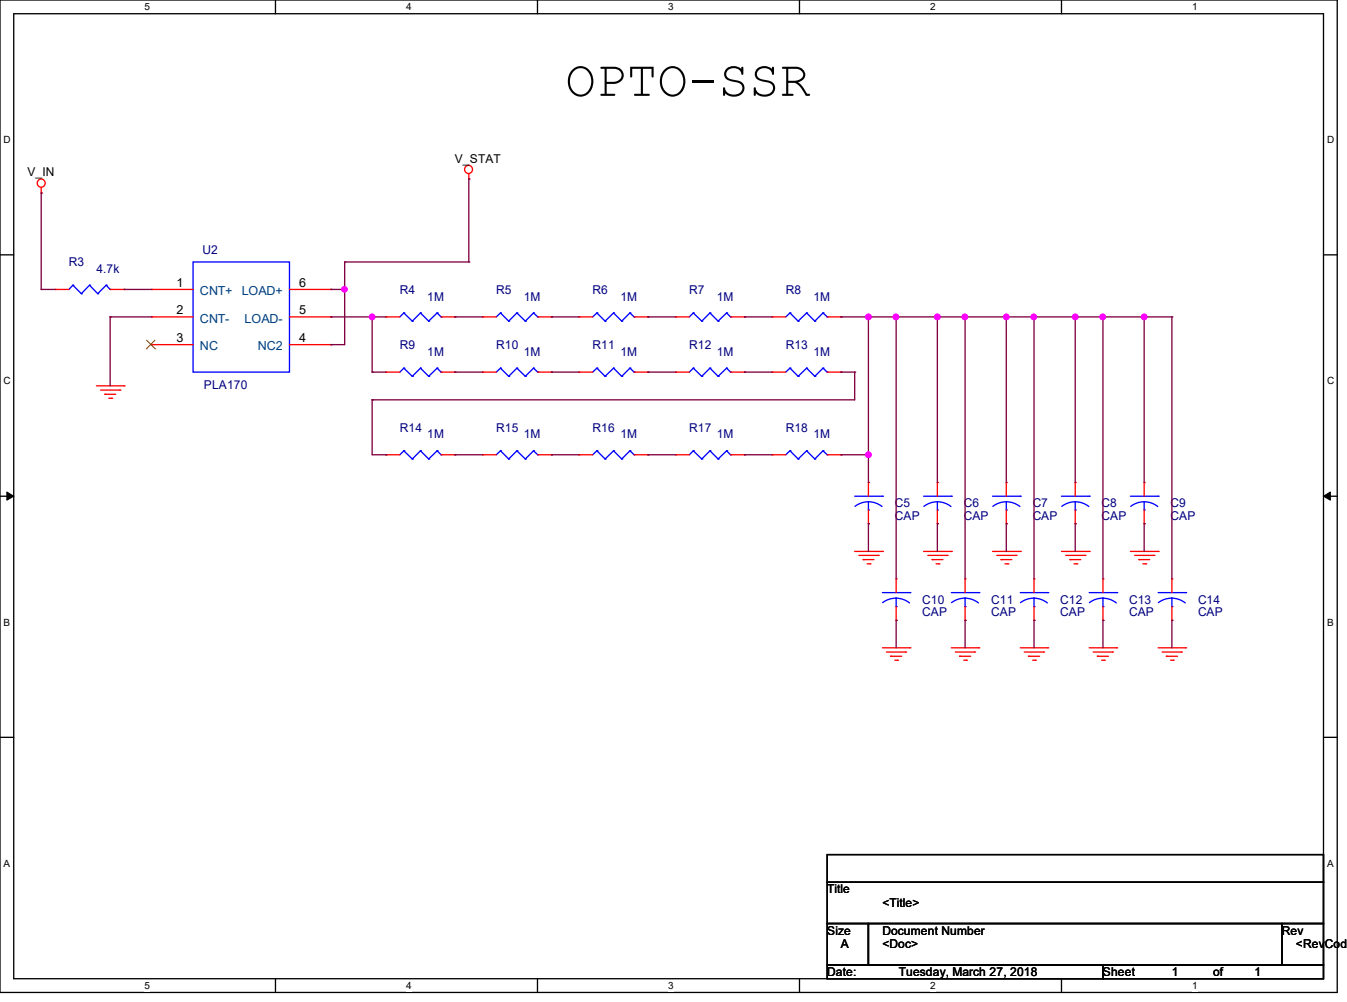
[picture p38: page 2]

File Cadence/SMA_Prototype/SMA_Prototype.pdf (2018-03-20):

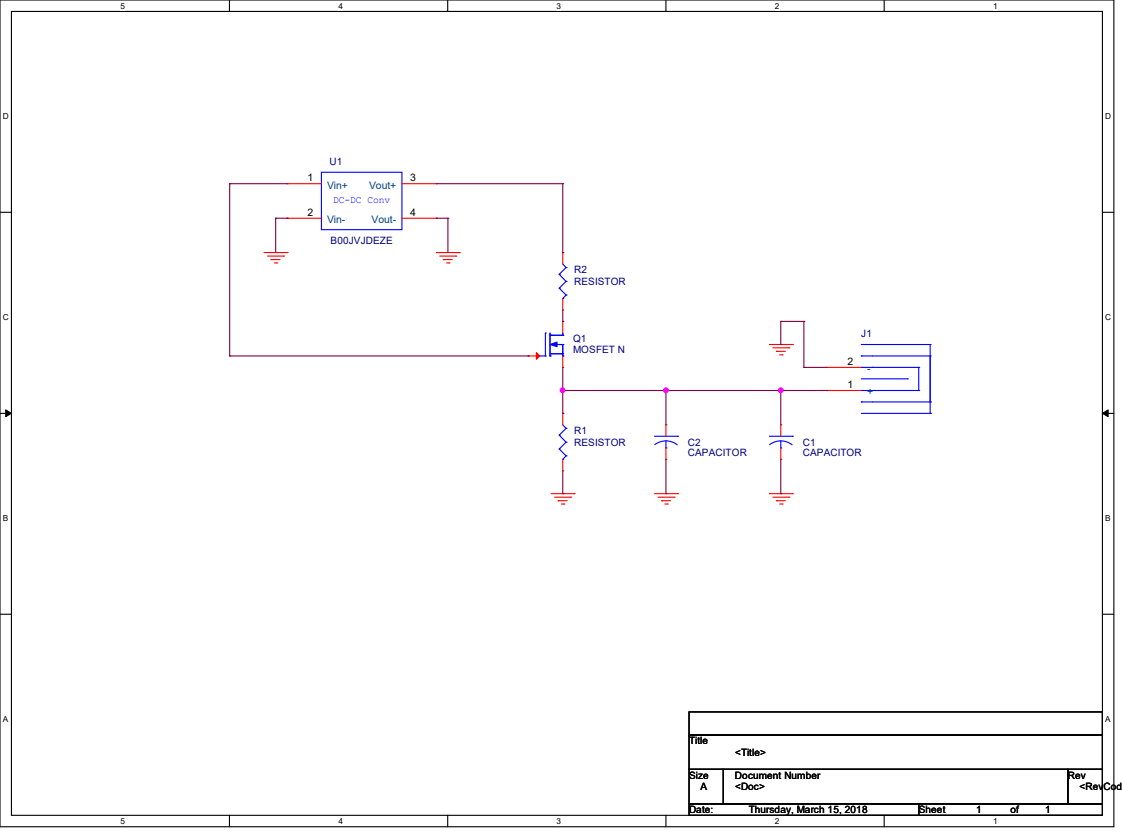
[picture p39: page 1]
A Title Size; Document Number; Rev Date:; Sheet; of <Doc>; <RevCode>; <Title> A; Thursday, March 15, 2018; 1 Title Size; Q1 MOSFET N; R1 RESISTOR; - 2 R2 RESISTOR; Vin+ 1 Vin- 2; Vout+ 3 Vout-; C1 CAPACITOR; C2 CAPACITOR

DC-DC Conv U1B00JVJDEZE

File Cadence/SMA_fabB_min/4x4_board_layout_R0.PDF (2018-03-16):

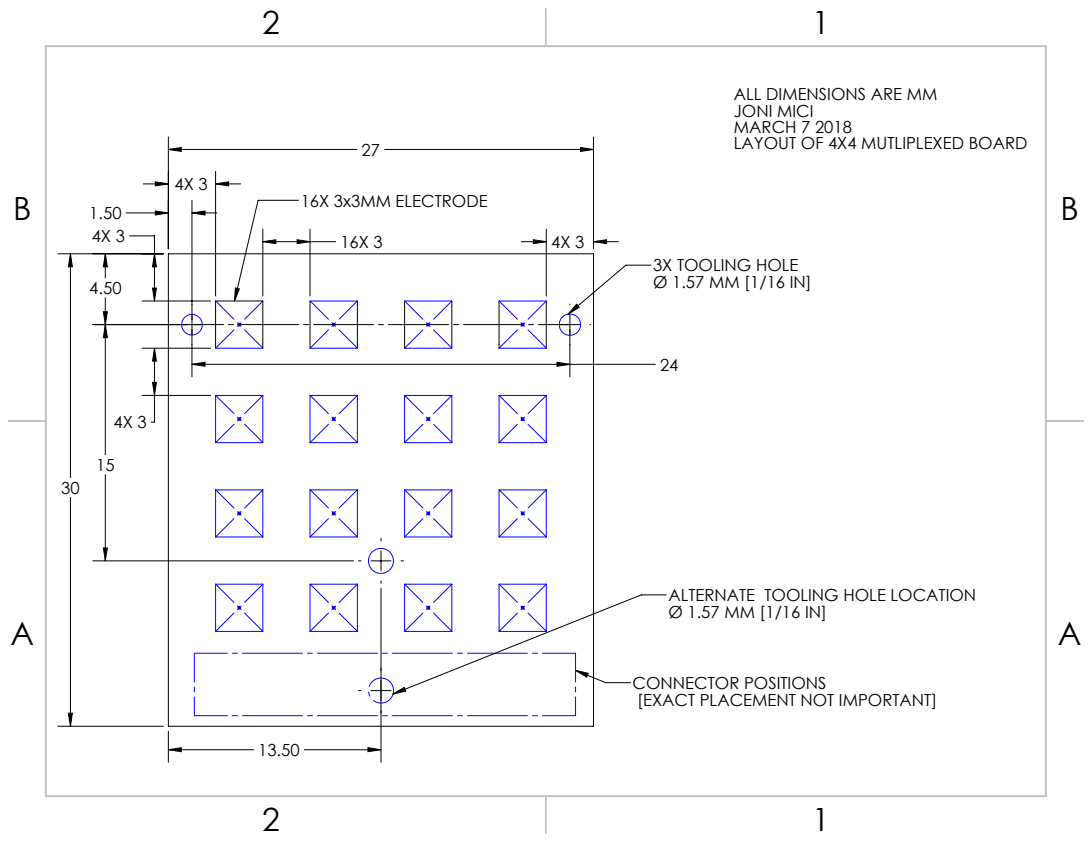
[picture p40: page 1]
3X TOOLING HOLE Ø 1.57 MM [1/16 IN]; 16X 3x3MM ELECTRODE

ALL DIMENSIONS ARE MM
JONI MICI
MARCH 7 2018
LAYOUT OF 4X4 MUTLIPLEXED BOARD

ALTERNATE TOOLING HOLE LOCATION

CONNECTOR POSITIONS
[EXACT PLACEMENT NOT IMPORTANT]

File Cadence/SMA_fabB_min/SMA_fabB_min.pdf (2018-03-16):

12V IN DC JACK | 12V TO 5V VR

# 5V TO V_STAT

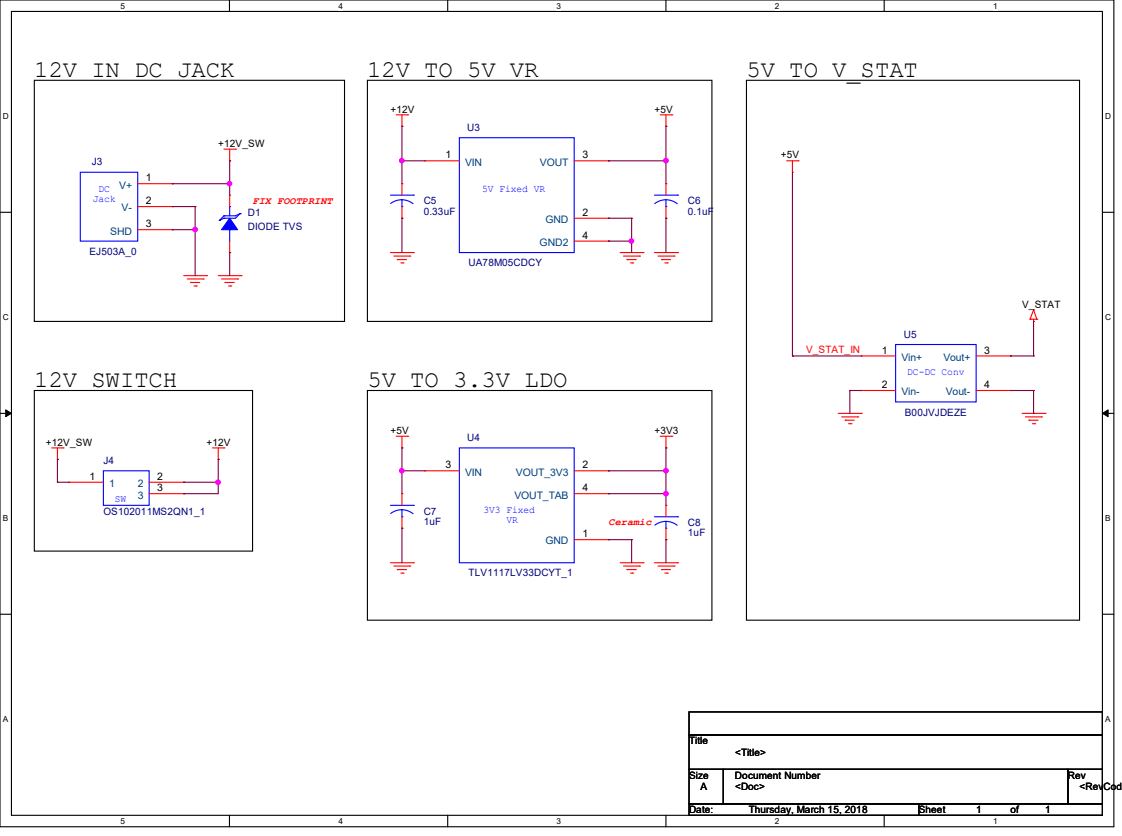
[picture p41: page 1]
12V SWITCH; 5V TO 3.3V LDO; Ceramic; FIX FOOTPRINT +12V_SW; V_STAT; Title Size; Document Number; Rev Date:; Sheet; of <Doc>; <RevCode>; <Title> A; Thursday, March 15, 2018; 1 Title Size; 0.1uF DIODE TVS; 5V Fixed VR U3UA78M05CDCY; VIN 1; VOUT 3 GND 2 GND2 4; DC Jack; 2 SHD 3; 3V3 Fixed; VR U4TLV1117LV33DCYT_1 VIN 3; VOUT_3V3 2 GND 1 VOUT_TAB 4; DC-DC Conv U5B00JVJDEZE; Vin+ 1 Vin- 2; Vout+ 3 Vout-; V_STAT_IN

# USB Type B Conn

# USB TO I2C BRIDGE

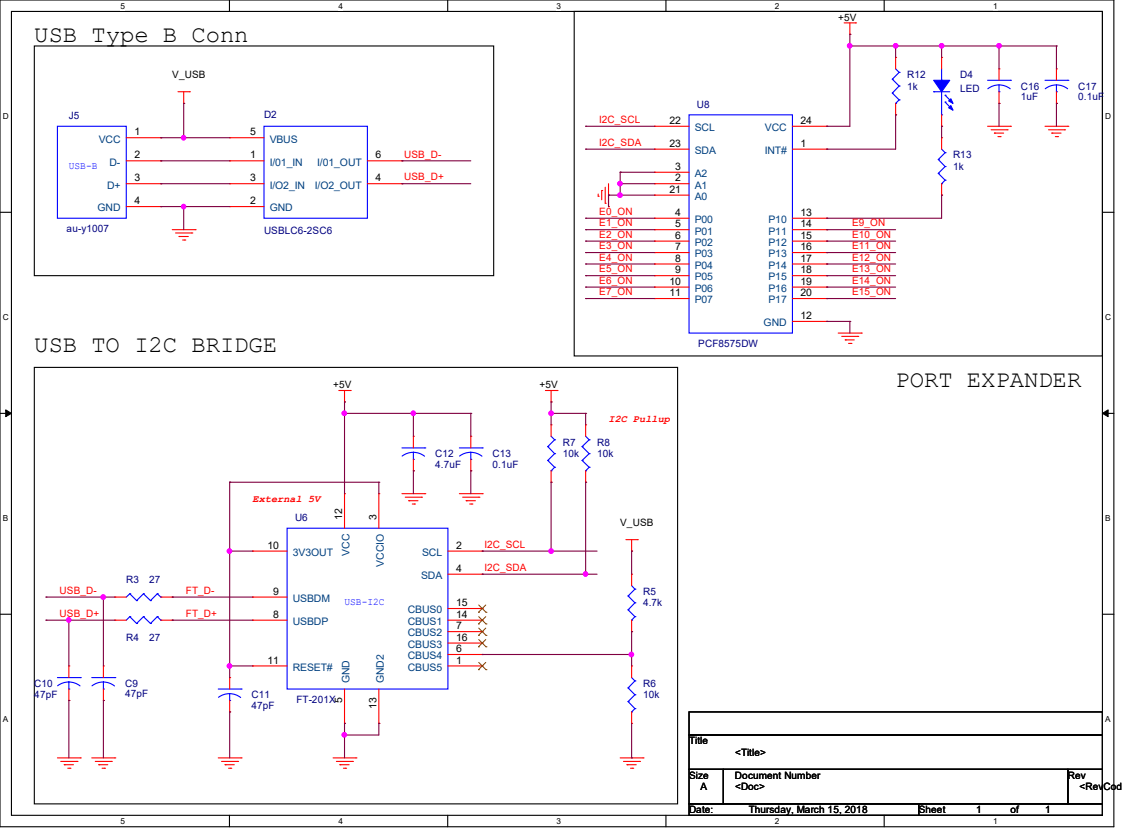
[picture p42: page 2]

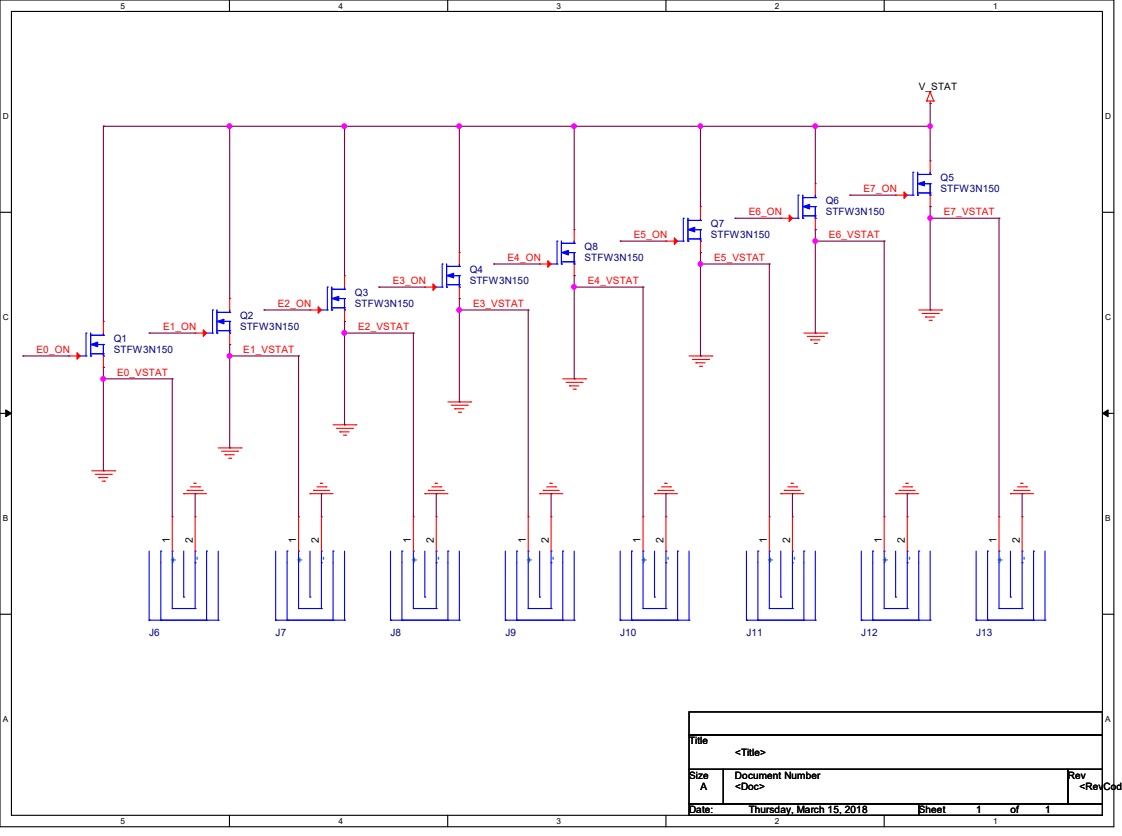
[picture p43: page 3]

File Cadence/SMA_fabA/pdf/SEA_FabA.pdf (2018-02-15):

EDGE CONNECTOR | COMB ELECTRODE x8 | SPIRAL ELECTRODE x8

J13+

Title; Size; Document Number; Rev; Date:; Sheet; Monday, February 12, 2018; edge_connector

A A SMART ELECTRODE ARRAY - FABA

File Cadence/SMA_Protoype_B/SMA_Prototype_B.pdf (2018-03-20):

# POWER

V_STAT; Title Size; Document Number; Rev Date:; Sheet; of <Doc>; <RevCode>; <Title> A; Tuesday, March 20, 2018; 1 Title Size; Vin+ 1 Vin- 2; Vout+ 3 Vout-

DC-DC Conv U1B00JVJDEZE

# PMOS-ONLY

V_STAT; Title Size; Document Number; Rev Date:; Sheet; of <Doc>; <RevCode>; <Title> A; Tuesday, March 20, 2018; 1 Title Size; C1 CAP Q1 MOSFET P; C2 CAP

# CMOS

V_STAT; Title Size; Document Number; Rev Date:; Sheet; of <Doc>; <RevCode>; <Title> A; Tuesday, March 20, 2018; 1 Title Size; C4 CAP U3 TC1550 SN 1 GN 2 SP 3 GP 4; C3 CAP

# OPTO-SSR

V_STAT; Title Size; Document Number; Rev Date:; Sheet; of <Doc>; <RevCode>; <Title> A; Tuesday, March 20, 2018; 1 Title Size; U2PLA170 CNT+ 1 CNT- 2 NC 3; LOAD-; LOAD+ 6 R3 4.7k


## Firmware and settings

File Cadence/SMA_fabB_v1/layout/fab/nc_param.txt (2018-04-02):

INTEGER-PLACES         2
DECIMAL-PLACES         5
X-OFFSET               0.000000
Y-OFFSET               0.000000
FEEDRATE               1
COORDINATES            ABSOLUTE
OUTPUT-UNITS           METRIC
TOOL-ORDER             INCREASING
REPEAT-CODES           YES
SUPPRESS-LEAD-ZEROES   NO
SUPPRESS-TRAIL-ZEROES  NO
SUPPRESS-EQUAL         NO
TOOL-SELECT            NO
OPTIMIZE_DRILLING      NO
ENHANCED_EXCELLON      NO
HEADER                 none
LEADER                 12
CODE                   ASCII
SEPARATE               NO
SEPARATE-ROUTING       NO
DRILLING               LAYER-PAIR
BACKDRILL              NO
CAVITY                 NO
COUNTER                NO
TOLERANCE_DRILL        NO
TOLERANCE_TRAVEL       NO
TOOL_SIZE              NO
ROTATION               YES
NON_STANDARD           NO
TOTAL_DRILL            NO
SEPARATE_SLOT          NO
SUPPRESS_TOLERANCE     NO
SUPPRESS_TOOLSIZE      NO
SUPPRESS_ROTATION      NO

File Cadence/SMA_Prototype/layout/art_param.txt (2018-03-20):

DEVICE-TYPE           GERBER_RS274X
OUTPUT-UNITS          INCHES
FILM-SIZE             240000 160000
FORMAT                2.4
ABORT-ON-ERROR        NO
SCALE                 1
SUPPRESS-LEAD-ZEROES  NO
SUPPRESS-TRAIL-ZEROES NO
SUPPRESS-EQUAL        NO
UNDEF-APT-CONT        NO

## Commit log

2018-02-15 Adding initial Cadence project
    [SEA_FABA.DSN, SMA_fabA - Copy.brd, SMA_fabA.brd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]
2018-02-16 Added comb electrode
    [comb_electrode.psm, sprial_electrode.psm, xsectionChartParams.txt]
2018-02-16 Ver 0.1 checkin
    [SMA_fabA - Copy.brd, SMA_fabA.dxf, cases.cfg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]
2018-02-16 Redid layout
    [SMA_fabA - Copy.brd, SMA_fabA.brd, comb_electrode.psm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]
2018-02-17 RFQ package
    [SMA_fabA - Copy.brd, SMA_fabA.brd, test.brd]
2018-02-18 Defined package footprints
    [020178 SEA BOM fabB.xls, Master Part Number List.xls, SEA_FABB.DSN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]
2018-02-18 Adding missing footprints
    [0603_r.psm, ft201x.psm, pcf8575dw.psm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]
2018-02-28 Fab B First Draft
    [SEA_FABB.DSN, os102011ms2qn1.psm]
2018-03-14 Outstanding changes
    [SMA_fabA.brd, edge_connector.psm]
2018-03-16 Prototype defined
    [SEA_FABB.DSN, SEA_FABB_MIN.DSN, SMA_PROTOTYPE.DSN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]
2018-03-20 Prototype B
    [SEA_FABB_MIN.DSN, SMA_PROTOTYPE.DSN, SMA_PROTOTYPE_B.DSN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]
2018-04-02 Fab B v1
    [033118 SEA BOM fabB.xls, 0603_r.psm, 1103m2s3cqe2.psm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]
2018-04-04 Fab B release
    [033118 SEA BOM fabB.xls, 040418 SEA BOM fabB (4pcb).xls, 040418 SEA BOM fabB.xls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]
2018-04-08 Added spiral
    [1206_r.psm, SEA_FABB_V1.DSN, SMA_fabB_v1_040418.brd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]
